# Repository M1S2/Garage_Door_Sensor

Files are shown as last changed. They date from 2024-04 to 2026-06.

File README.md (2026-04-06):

# Garage Door Sensor

This is a project to send the status of multiple garage doors (or equal) to one indoor station. This is useful if the door can't be seen from inside.
Each device (sensor and indoor station) uses an ESP12-F (ESP8266) controller that runs the software and is the WiFi transmitter. The data between the sensor and the indoor station is transmitted using ESP-Now. The indoor station acts as a gateway between ESP-Now and WiFi.

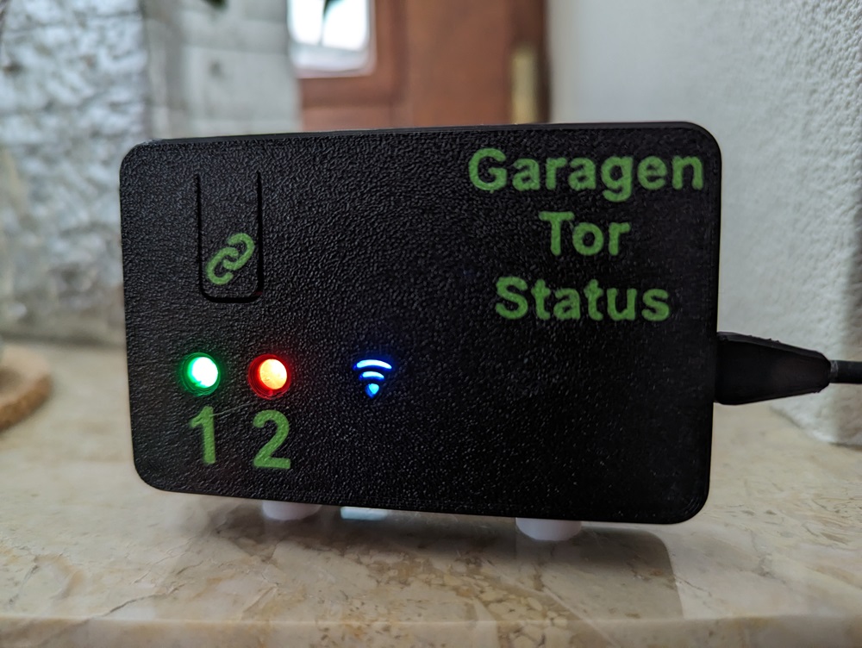
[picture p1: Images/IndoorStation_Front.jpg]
Indoor Station Front


## Building the Indoor Station
You need to build only one indoor station. It receives the state of all door sensors. The current version of the indoor station is capable of displaying 2 sensors at the same time. If you need more sensors, the indoor station must be adapted.

### PCBs and Housing
The PCBs are designed using Autodesk Fusion360 to be manufactured with toner transfer method. All design files are located in the [Electrical files for IndoorStation](IndoorStation/Electrical) subfolder.

The housing parts are also designed using Autodesk Fusion360 to be manufactured with a 3D printer. All files are located in the [Mechanical files for IndoorStation](IndoorStation/Mechanical) subfolder. Each part is needed once except the Stand (needed twice).

Also the following additional parts are necessary:
- 4x Screw M3x20
- 2x Screw M3x10
- 6x Heat Insert M3x5x5
- some acrylic glass to cover and diffuse the LEDs
- DC Power Supply (voltage e.g. 5V, is regulated down to 3.3V)

The following image shows all parts of the IndoorStation:
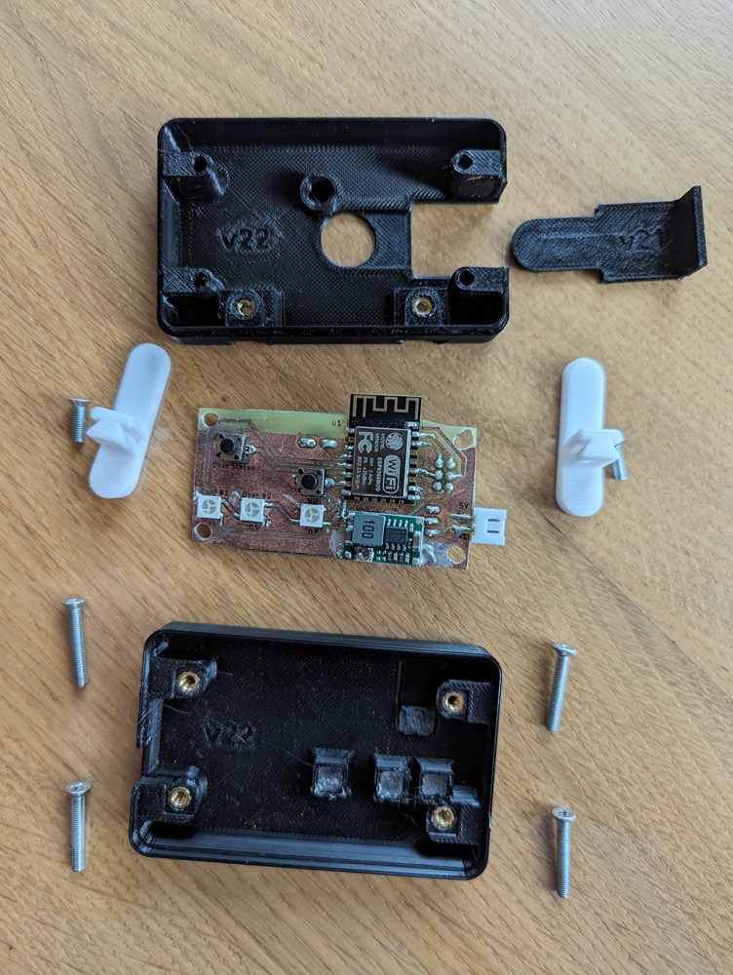
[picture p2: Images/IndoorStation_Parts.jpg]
IndoorStation Parts


### Software
The software files are located in the [Software files for IndoorStation](IndoorStation/Software) subfolder.

To build and flash the lastest software to the IndoorStation ESP12-F download and install Visual Studio Code and install the PlatformIO extension. The following page explains the whole process: https://randomnerdtutorials.com/vs-code-platformio-ide-esp32-esp8266-arduino/

The following parts must be flashed:
- Firmware: Use the `Build` and `Upload` PlatformIO tasks.
- Filesystem (containing the website files): Use the `Build Filesystem Image` and `Upload Filesystem Image` PlatformIO tasks.

## Building the Sensor
You need to build one sensor per door to monitor. The current version of the indoor station is capable of displaying 2 sensors at the same time. If you need more sensors, the indoor station must be adapted. No changes to the sensor are necessary.
### PCBs and Housing
The PCBs are designed using Autodesk Fusion360 to be manufactured with toner transfer method. All design files are located in the [Electrical files for sensor](Sensor/Electrical) subfolder.

The housing parts are also designed using Autodesk Fusion360 to be manufactured with a 3D printer. All files are located in the [Mechanical files for sensor](Sensor/Mechanical) subfolder. Each part is needed once.

Also the following additional parts are necessary:
- 4x Screw M3x30
- 4x Heat Inserts M3x5x5
- 1x Li-Ion 18650 (e.g. https://www.roboter-bausatz.de/p/bak-18650-lithium-ionen-akku-2900mah-3-6v-3-7v-erhoehter-pluspol)
- 1x Charge Modul USB-C (e.g. https://www.roboter-bausatz.de/p/lithium-batterie-lademodul-usb-c-ip2312-4-2v-5v)
- 2x Magnet for Door Mount

The following image shows all parts of the Sensor:
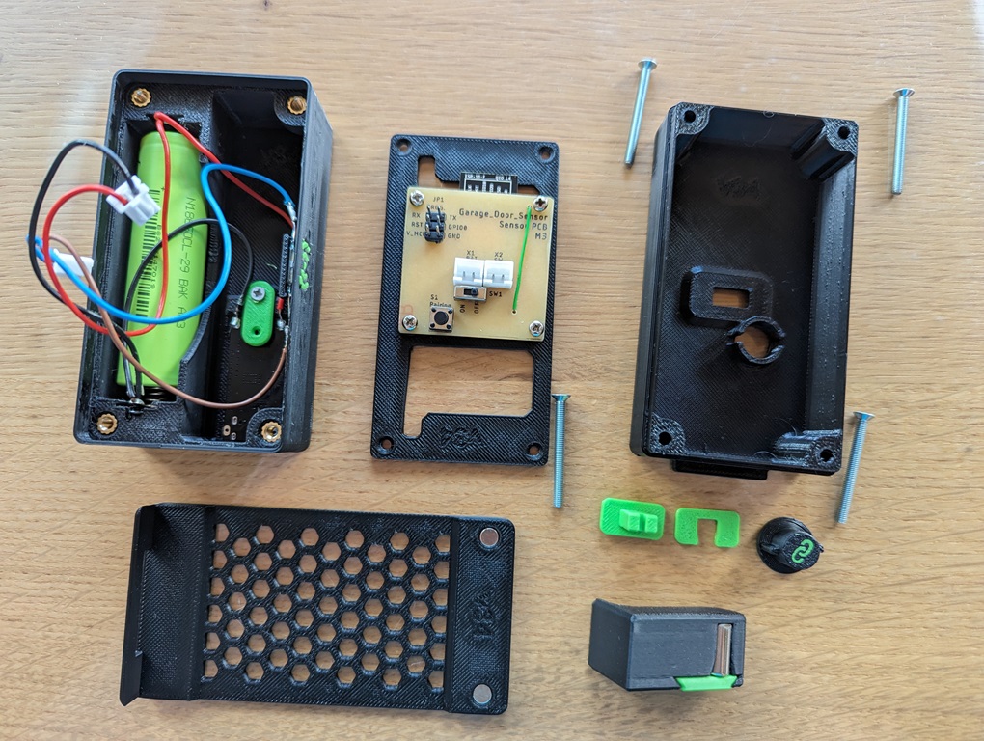
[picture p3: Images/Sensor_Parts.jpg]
Sensor Parts


### Software
The software files are located in the [Software files for Sensor](Sensor/Software) subfolder.

To build and flash the lastest software to the sensor ESP12-F download and install Visual Studio Code and install the PlatformIO extension. The following page explains the whole process: https://randomnerdtutorials.com/vs-code-platformio-ide-esp32-esp8266-arduino/

## Usage
This chapter describes the basic usage of the indoor station and sensor. It is necessary to build at least one device each before proceding.
### Charging the sensor
Switch off the sensor via the switch on the back side and connect it to an USB-C charger. Make sure the charger is capable of delivering enough energy. Otherwise the charging process will be slow.

Charger LED states:

|LED		|Meaning		|
|---|---|
|Red solid	|Powered via USB-C	|
|Green solid	|Charging complete	|

### WiFi Setup
The indoor station isn't yet connected to your local WiFi the first time you use it or after a reset.
It is necessary to connect it to the WiFi. Otherwise the following steps can't be done and the indoor station can't receive the sensor messages.
1. Power the indoor station.
2. The WiFi LED will start flashing blue for about 5 seconds (indicating that it's trying to set up a connection).
3. After this timeout, the WiFi LED will change to white, indicating that the indoor station entered access point configuration mode.
4. Search for all available WiFi networks with your smartphone or computer and connect to the one called "Garagen Tor Status AP" (configuration access point).
5. After connecting to the configuration access point, a captive portal pops up automatically (sometimes needs some seconds; otherwise directly open the IP 192.168.4.1 in your browser).
6. Select your routers WiFi network and enter the password.
7. After confirmation, the indoor station restarts and the WiFi LED is flashing blue again until the connection to the router is established.
8. When successfully connected to the WiFi, the WiFi LED is solid blue.

### Pairing of the Sensor
The pairing of the sensor can be done via the pairing button of the indoor station and the pairing button of the corresponding sensor.
1. Press the pairing button on the indoor station long. The first sensor led will start to flash blue and red.
2. Press the pairing button on the indoor station short to select the sensor slot you want to pair.
3. When the indoor station mode for the correct sensor is pairing, press and hold the pairing button on the sensor for at least 5 seconds (sensor must be switched on).
4. If the pairing of the sensor was successful, the indoor station stopped to flash blue and red.

Repeat all steps for all sensors.

**Alternative:**

The pairing of the sensor can also be done via the web pages of the indoor station.
1. Open the web page (with one of the following ways):
   a) Enter the IP address that was assigned by your router in the address bar of your browser.
   b) For Fritz!Box: enter the following host name in the address bar of your browser: `garagen-tor-status.fritz.box` (or scan the QR code below)
2. Change to the configuration page (gear icon)
3. Enter the MAC address of the sensor to pair in the textbox of the corresponding sensor and click submit.
4. All messages of this sensor are now received for the sensor index where the MAC address was entered.

Repeat steps 3. and 4. for all sensors.

Indoor Station web page QR Code

### Mounting the Sensor and Magnet
To mount the sensor and magnet to the garage door:
1. Insert a magnet inside the `Magnet_Mount` part and assemble the `Magnet_Mount_Lid` with a screw.
2. Take the full assembled sensor, the `Door_Mount` part and the `Magnet_Mount`.
3. Switch off the sensor using the switch on the back side.
4. Go inside the garage and close the door.
5. Fix the `Door_Mount` part with double sided tape or power stripes to the door frame. Make sure, there is a small gap of about 3 mm to the metal blade of the door (the outermost moving part). An example position is shown in the following pictures:
6. Insert the sensor in the `Door_Mount`. The two magnets on the `Door_Mount` hold the sensor in place. The counterparts are the two upper screws in the sensor housing.
7. Fix the `Magnet_Mount` part with double sided tape or power stripes to the door blade. Make sure, the magnet is near the icon on the side of the sensor (indicating the position of the reed switch).
8. Open and close the door to make sure, the magnet is moved from and to the sensor, without any mechanical contact. If the door is closed, the magnet must reside near the sensor again.
9. Remove the sensor from the `Door_Mount`, switch the sensor on using the switch on the back side and insert the sensor in the `Door_Mount` again.

<p>
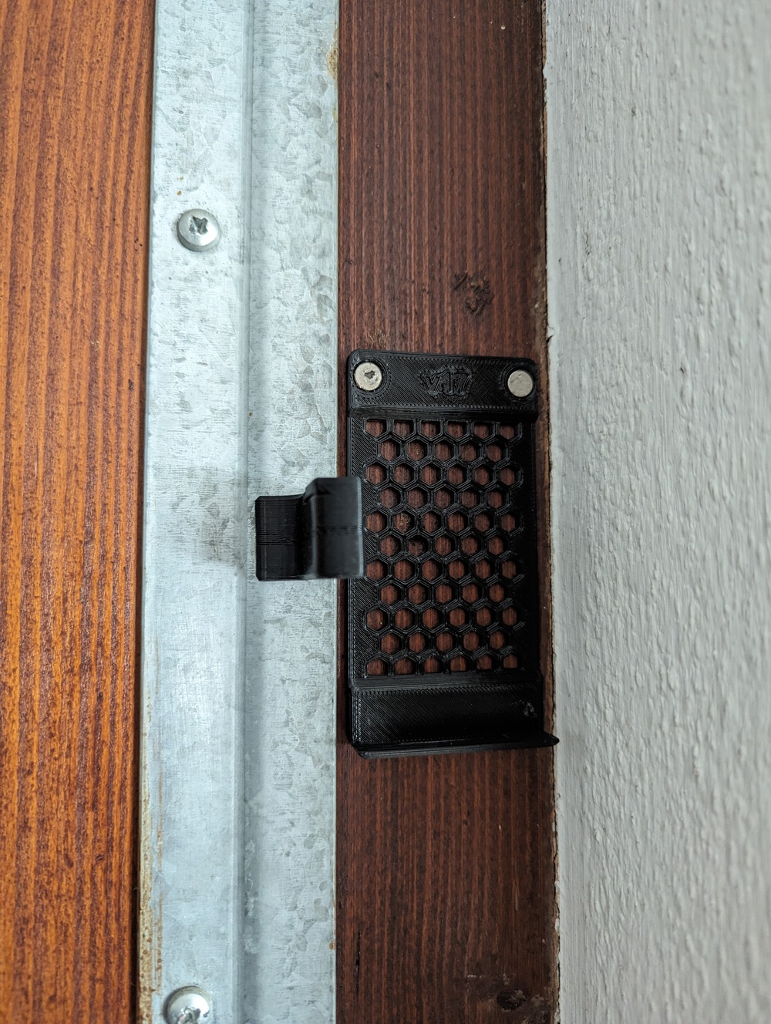
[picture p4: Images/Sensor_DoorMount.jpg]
  
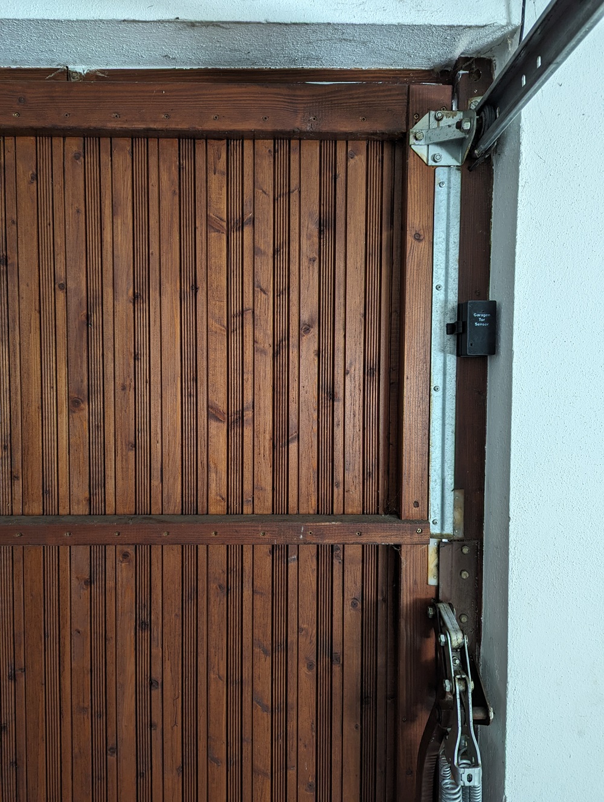
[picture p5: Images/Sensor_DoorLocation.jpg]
  
</p>

### Testing
To test the whole system, open and close one garage door after another and monitor the displayed state on the indoor station.
- When the first door is closed, the LED "1" on the indoor station will be red.
- When the first door is open, the LED "1" on the indoor station will be green.
- When the second door is closed, the LED "2" on the indoor station will be red.
- When the second door is open, the LED "2" on the indoor station will be green.
- All actual door states can also be monitored via the web page (overview page). To open the the web page, follow the steps at the ["Pairing the sensor" chapter](#pairing-of-the-sensor).

## LED States
| Led		 | Color 	 | State | Description						 |
|---|---|---|---|
| Sensor #1 / #2 | red 		 | solid | Door is closed, battery ok 				 |
| Sensor #1 / #2 | red 		 | flashing | Door is closed, battery empty 				 |
| Sensor #1 / #2 | green 	 | solid | Door is open, battery ok 					 |
| Sensor #1 / #2 | green 	 | flashing | Door is open, battery empty 				 |
| Sensor #1 / #2 | purple 	  | solid | Sensor mode is charging 					 |
| Sensor #1 / #2 | red / blue	| blinking | Sensor mode is pairing 					 |
| Sensor #1 / #2 | / 		 |  off | Either no message received yet, or sensor mode is disabled |
| Wifi  	 | blue 	 | flashing | Trying to connect to WiFi 				 	|
| Wifi  	 | blue 	 | solid | Connected to WiFi 					 |
| Wifi  	 | red 		 | solid | Connection to WiFi failed 				 |
| Wifi  	 | white 	 | solid | Configuration access point is open 			 |
| All  		 | yellow 	  | blinking | OTA Update is in progress 					 |
| All  		 | green 	 | solid | OTA Update is in ready 					 |
| All  		 | red 		 | solid | OTA Update is in failed 					 |

## Button Reactions:
| Button  | Click Type  | Precondition | Description |
|---|---|---|---|
| Reset | long press  | always | Memory data and WiFi credentials are erased |
| Pairing | long press  | no sensor is in pairing mode | Set first sensor to pairing mode (start pairing) |
| Pairing | long press  | at least one sensor is in pairing mode  | Set all sensors that are in pairing mode back to normal mode (end pairing)  |
| Pairing | short click | no sensor is in pairing mode | Do nothing |
| Pairing | short click | at least one sensor is in pairing mode  | Find the first sensor with pairing mode. Set it to normal mode and set the next sensor to pairing mode. If it was the last sensor begin with the first again. |

## Sensor Modes
| Mode 		 | Description 													 				|
|---|---|
| Normal	 | All messages are received, everything is saved, LED on								 			|
| Disabled	 | All messages are ignored, nothing is saved, LED off										 		|
| Charging	 | All messages are ignored, nothing is saved, LED in different color								 		|
| Only Display  | Messages are only displayed via the LED, nothing is saved											 |
| Pairing	 | Message from Indoor Station to corresponding sensor to configure the MAC address in the sensor, LED flashes red and blue, nothing is saved	  |

## Developer Hints
- The sensor is designed to consume as less power as possible. Therefore the ESP8266 on the sensor is only switched on when the pin state changed and only as long until the data is sent to the indoor station.
- The sensor trys to send the data on all available WiFi channels until success. The most common used channels are tried first.
- The indoor station can be updated using over the air (OTA) updates. The first time the firmware must be flashed via serial, the OTA is available by navigating to `garagen-tor-status.fritz.box/update` in the browser.
- Accessing the indoor station web pages via the IP address (e.g. 192.168.x.x) isn't really intuitive. The FritzBox offers the possibility to alternatively navigate to `garagen-tor-status.fritz.box`. The correct IP address is then resolved via DNS.

## Further Improvements
- Move the pairing button of the Indoor Station to the backside of the housing (not used very often, cleaner front side) 
- Remove ConnectorLid of Indoor Station housing (software updates are possible via OTA, no need to open the housing very often)
- Remove the on/off switch from the Indoor Station PCB (not really used, disconnecting power supply is enough)

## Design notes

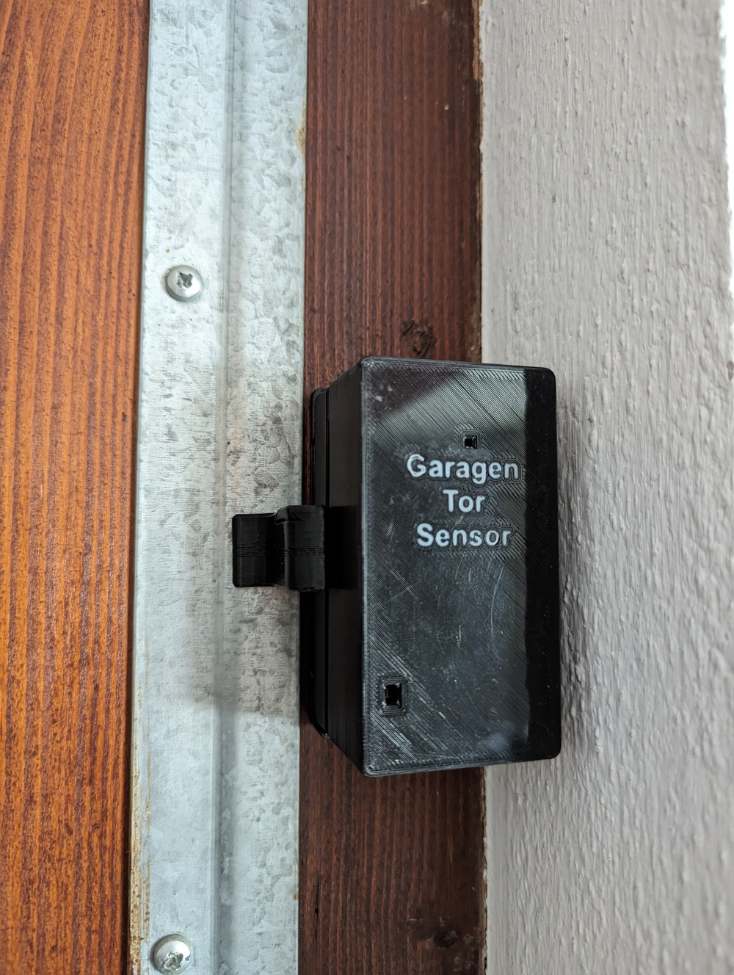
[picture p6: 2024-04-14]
Images/Sensor_DoorClosed_MagnetHolder.jpg

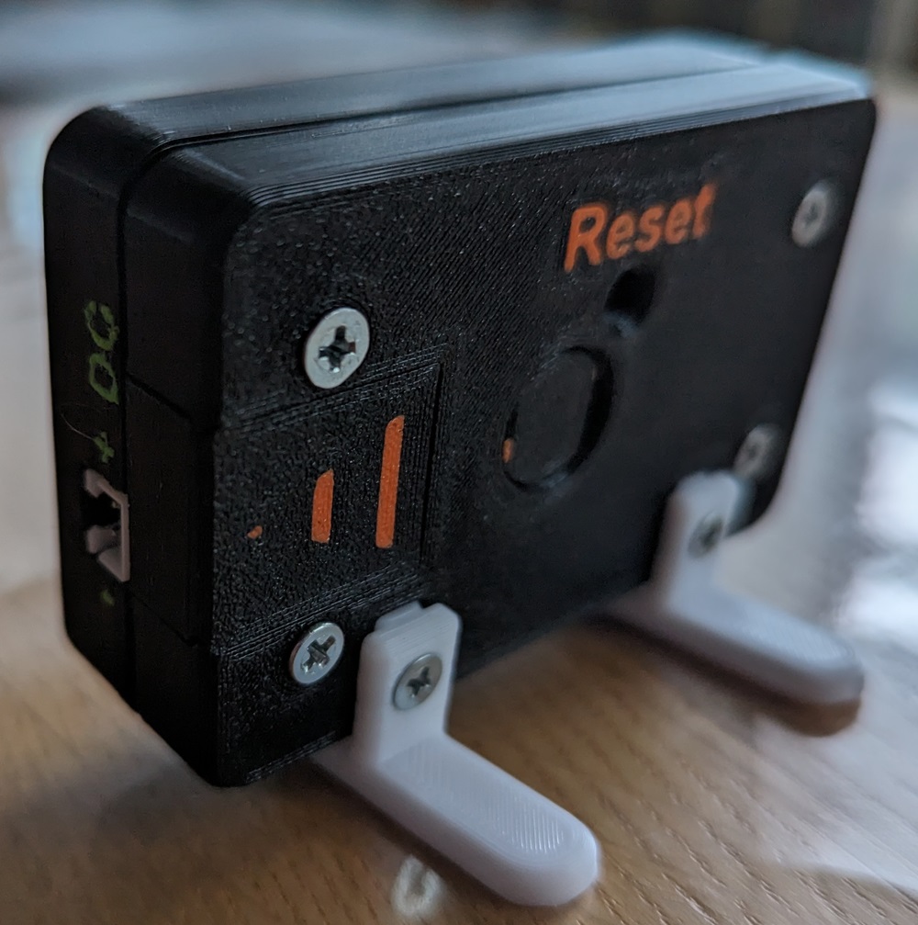
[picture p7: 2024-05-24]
Images/IndoorStation_Back.jpg

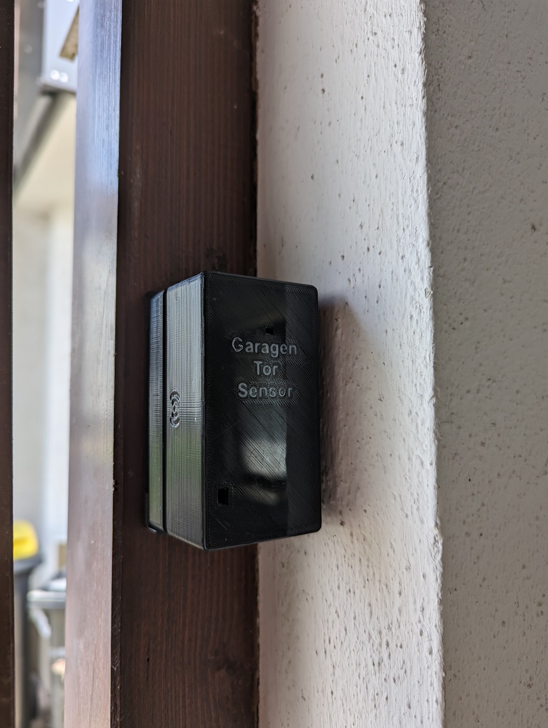
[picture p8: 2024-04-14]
Images/Sensor_DoorOpen.jpg

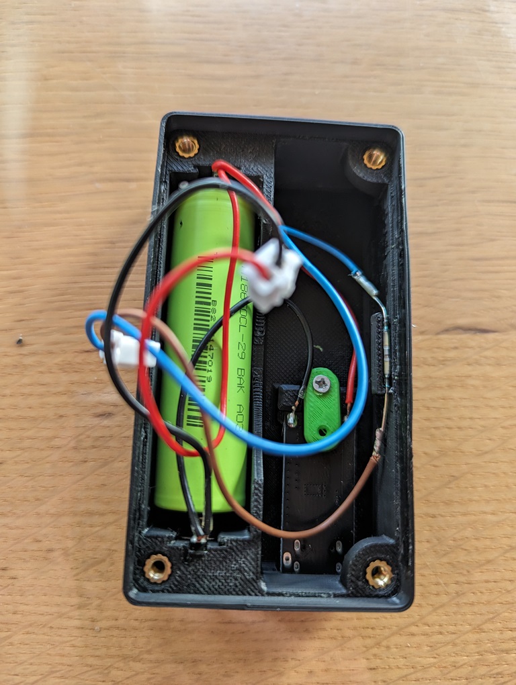
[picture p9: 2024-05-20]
Images/Sensor_FrontLid_Battery.jpg

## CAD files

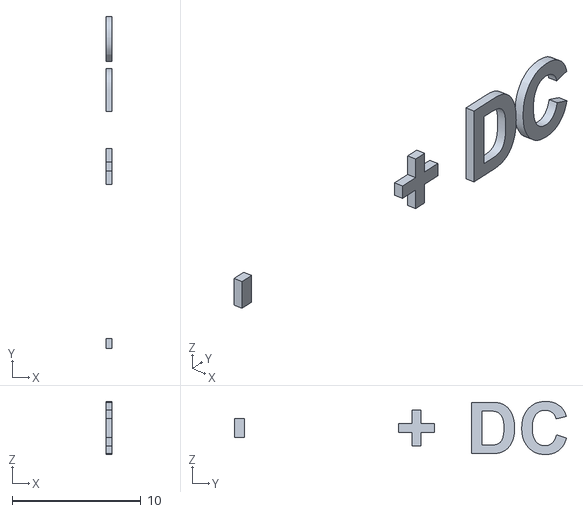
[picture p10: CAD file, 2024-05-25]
IndoorStation/Mechanical/Front_Lid_Text_Side_M3.stl
0.5 x 25.8 x 4.14

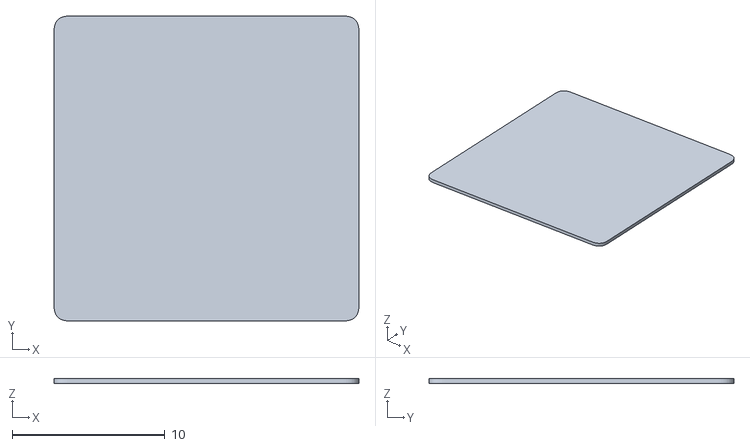
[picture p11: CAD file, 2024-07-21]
IndoorStation/Mechanical/QR_Code/qrcode-base.stl
20.0 x 20.0 x 0.3

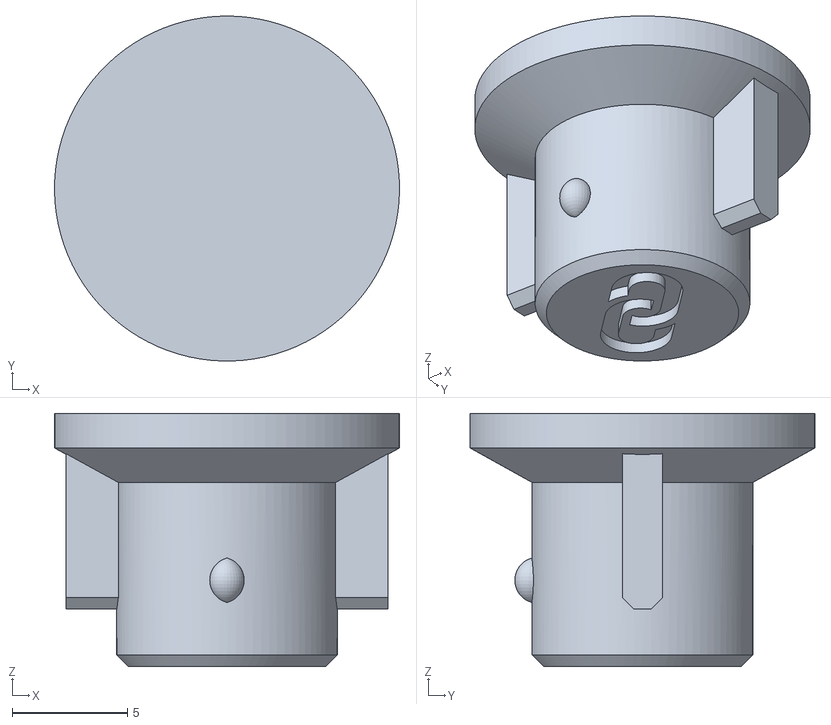
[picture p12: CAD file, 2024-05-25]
Sensor/Mechanical/Pairing_Button_M3.stl
15.0 x 15.0 x 11.0

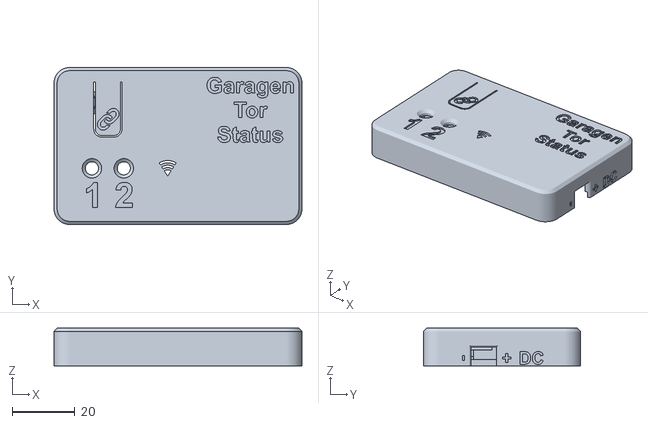
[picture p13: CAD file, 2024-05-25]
IndoorStation/Mechanical/Front_Lid_M3.stl
79.0 x 50.0 x 12.0

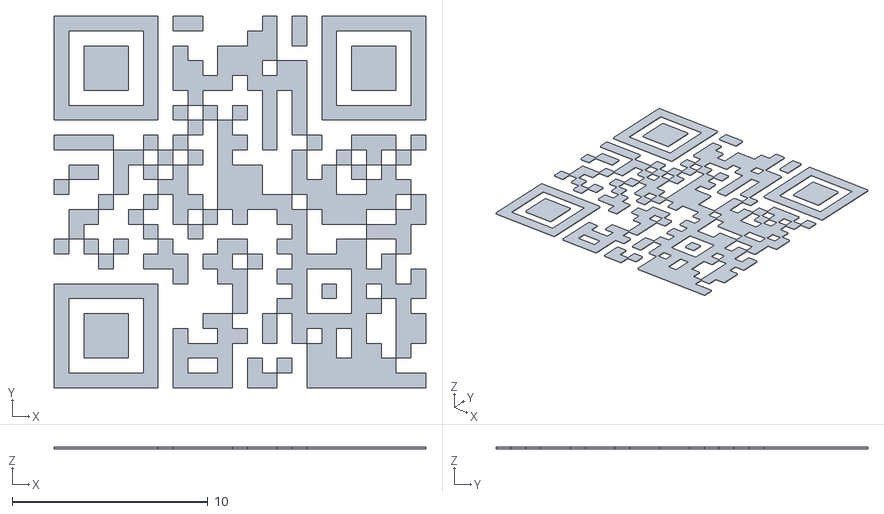
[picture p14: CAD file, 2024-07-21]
IndoorStation/Mechanical/QR_Code/qrcode.stl
19.0 x 19.0 x 0.1

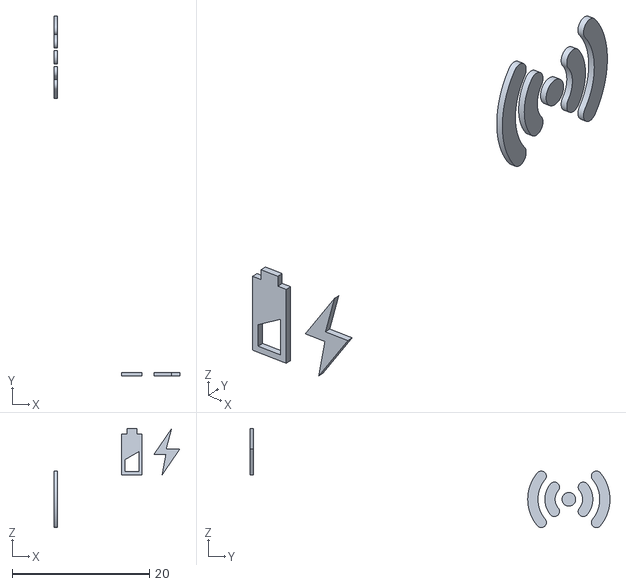
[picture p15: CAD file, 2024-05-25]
Sensor/Mechanical/Front_Lid_Text_Side_M3.stl
18.4 x 52.5 x 14.5

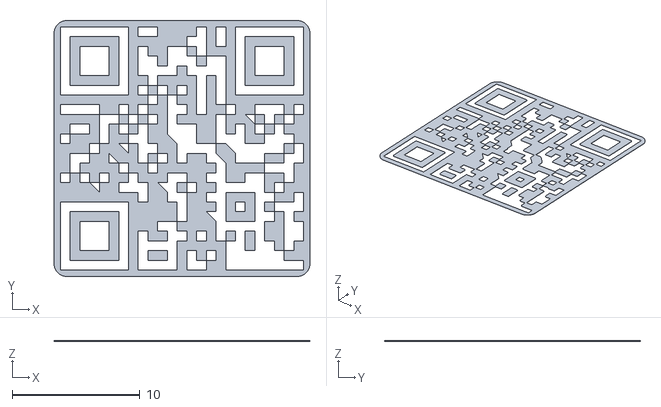
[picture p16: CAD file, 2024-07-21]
IndoorStation/Mechanical/QR_Code/qrcode-frame.stl
20.0 x 20.0 x 0.1

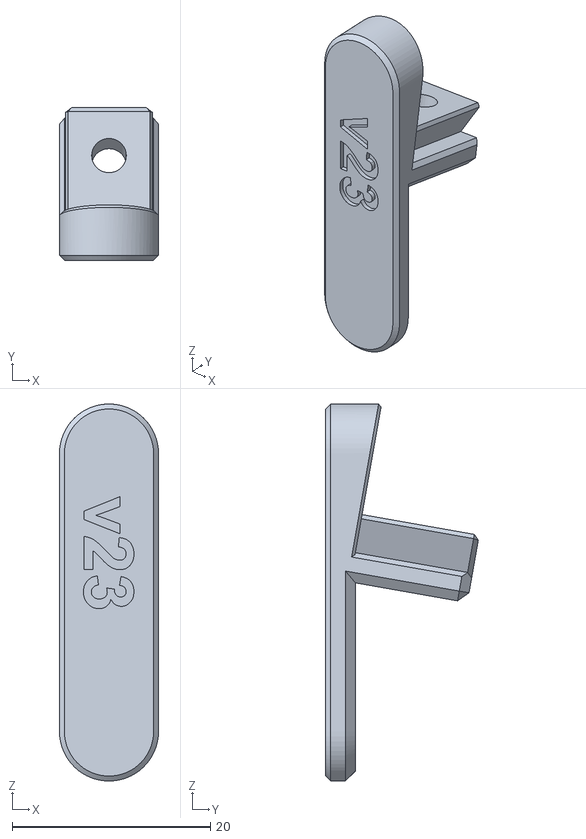
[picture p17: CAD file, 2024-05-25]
IndoorStation/Mechanical/Stand_M3.stl
10.0 x 15.4 x 38.0

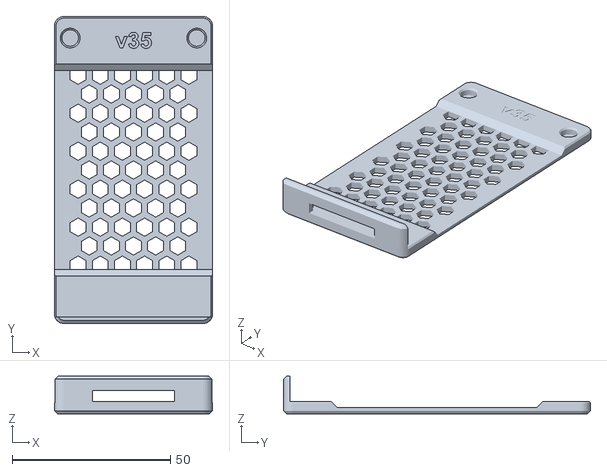
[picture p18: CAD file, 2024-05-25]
Sensor/Mechanical/Door_Mount_M3.stl
50.0 x 97.0 x 12.0

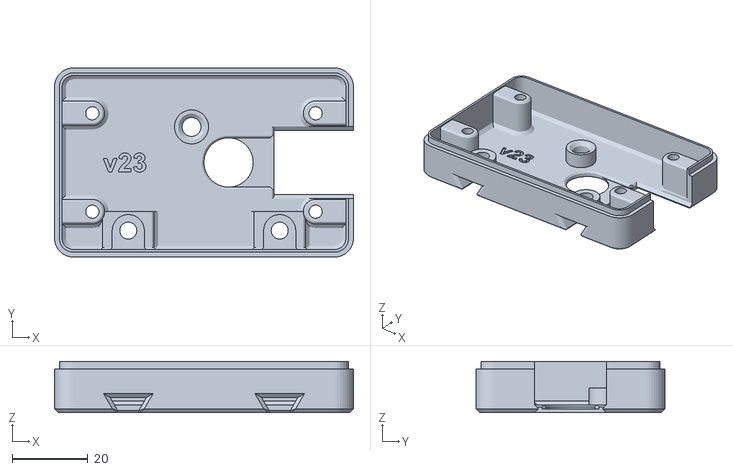
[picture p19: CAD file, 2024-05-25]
IndoorStation/Mechanical/Back_Lid_M3.stl
79.0 x 50.0 x 13.5

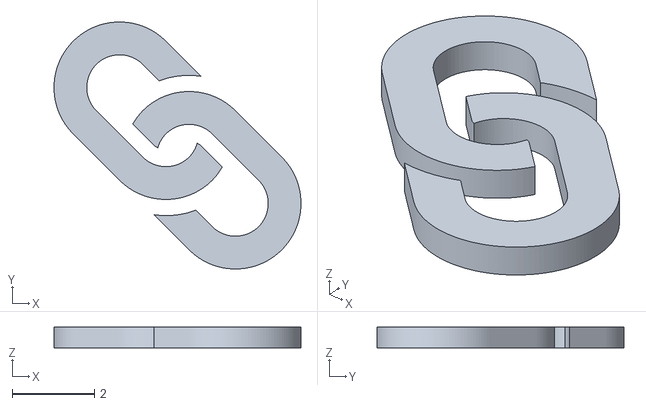
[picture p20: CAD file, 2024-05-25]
Sensor/Mechanical/Pairing_Button_Text_M3.stl
6.02 x 6.02 x 0.5

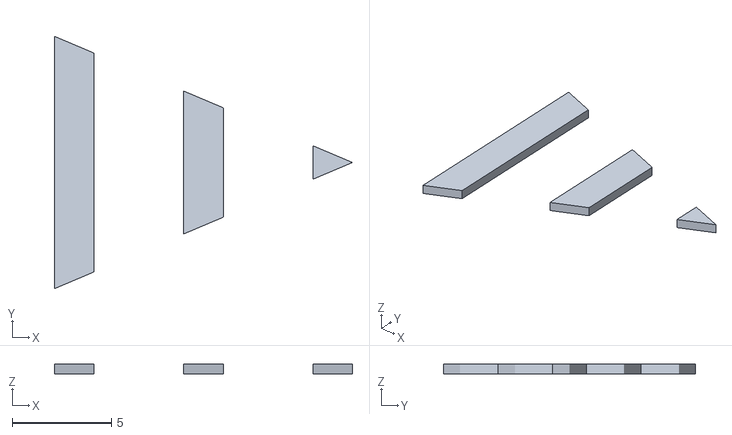
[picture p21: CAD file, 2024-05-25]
IndoorStation/Mechanical/Connector_Lid_Text_M3.stl
15.0 x 12.7 x 0.5

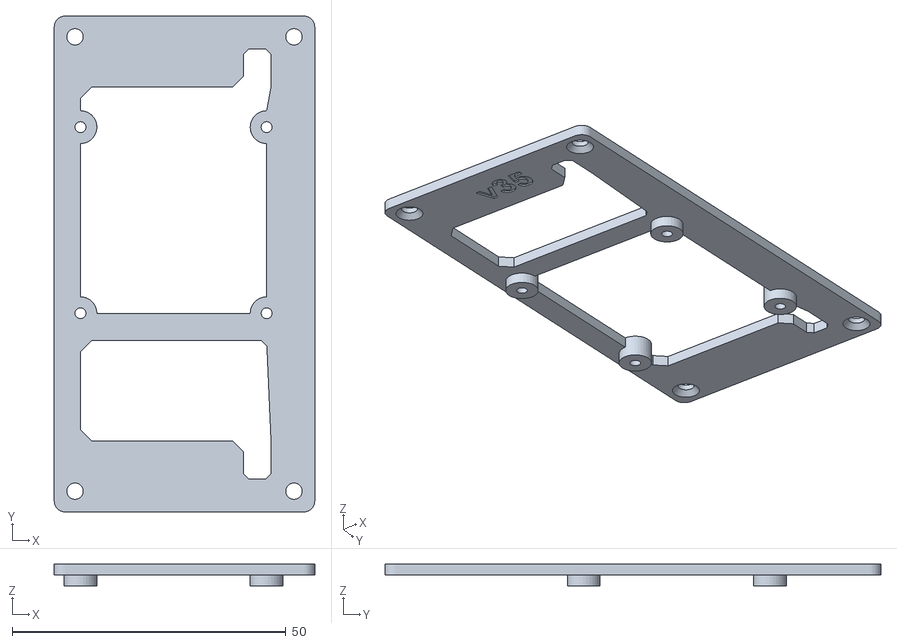
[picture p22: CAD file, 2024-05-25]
Sensor/Mechanical/PCB_Holder_M3.stl
47.6 x 90.6 x 4.00

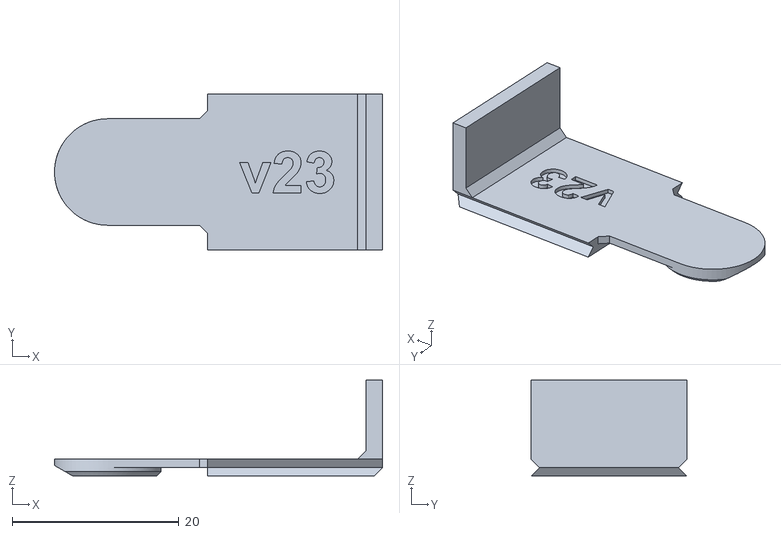
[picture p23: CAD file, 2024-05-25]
IndoorStation/Mechanical/Connector_Lid_M3.stl
39.4 x 18.7 x 11.5

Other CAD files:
Sensor/Mechanical/Back_Lid_M3.stl
IndoorStation/Mechanical/Back_Lid_Text_M3.stl
Sensor/Mechanical/Front_Lid_M3.stl
IndoorStation/Mechanical/Front_Lid_Text_M3.stl
IndoorStation/Mechanical/Back_Lid_M3.f3d
IndoorStation/Mechanical/Connector_Lid_M3.f3d
IndoorStation/Mechanical/Front_Lid_M3.f3d
IndoorStation/Mechanical/Stand_M3.f3d
Sensor/Mechanical/Back_Lid_M3.f3d
Sensor/Mechanical/Back_Lid_Text_M3.stl
Sensor/Mechanical/Door_Mount_M3.f3d
Sensor/Mechanical/Front_Lid_M3.f3d
Sensor/Mechanical/Front_Lid_Text_M3.stl
Sensor/Mechanical/LoadingModuleClamp_M3.f3d
Sensor/Mechanical/LoadingModuleClamp_M3.stl
Sensor/Mechanical/Magnet_Mount_Lid_M3.f3d
Sensor/Mechanical/Magnet_Mount_Lid_M3.stl
Sensor/Mechanical/Magnet_Mount_M3.f3d
Sensor/Mechanical/Magnet_Mount_M3.stl
Sensor/Mechanical/Pairing_Button_M3.f3d
Sensor/Mechanical/Switch_Slider_Clamp_M3.f3d
Sensor/Mechanical/Switch_Slider_Clamp_M3.stl
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

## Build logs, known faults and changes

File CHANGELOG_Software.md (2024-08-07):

# Garagen Door Sensor - Software Changelog

## v2.3

> Sensor
- Nothing changed (equal to v2.2)

> Indoor Station
- Added a QR code for the indoor station web page to the Readme
- Adaptions to the Readme
- Bugfix for sensor_history.js (chart was incomplete or contained wrong data when incomplete chunks were received)
- Added version tag for the webpages

## v2.2

> Sensor
- Disabled debug output to save power

> Indoor Station
- Added define to disable debug output

## v2.1

> Sensor
- Nothing changed (equal to v2.0)

> Indoor Station
- Make sure that all data is displayed in all charts after updating
- Removed data labels from charts
- Bugfixes for reset

> Documentation
- Update README.md (color for charging LED)
- Updated some images for Readme

## v2.0

> Sensor & Indoor Station
- Added feature to pair sensor with indoor station (send sensor MAC to indoor station)

> Sensor
- Combine methods to send pairing and status data
- Switch off and on Wifi to improve ADC accuracy

> Indoor Station
- Reactivated and renamed button to select pairing mode

> Documentation
- Updated Readme and some images

## v1.0

> Sensor
- Initial version

> Indoor Station
- Initial version

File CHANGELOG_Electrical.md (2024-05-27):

# Garagen Door Sensor - Electrical Changelog

## PCB_M3

> Sensor
- Added pairing switch

> Indoor Station
- Changed name of show status button to pairing button
- Removed WiFi button

## PCB_M2

> Sensor
- Added resistor R10 (pull-down for door switch)
- Added hole markers

> Indoor Station
- Added vias to button pads for better assembly
- Added hole markers

## PCB_M1

> Sensor
- Initial version

> Indoor Station
- Initial version

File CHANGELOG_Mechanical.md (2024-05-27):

# Garagen Door Sensor - Mechanical Changelog

## HW_M3

> Sensor
- Made pairing button slightly shorter

> Indoor Station
- Slight adaptions to Front_Lid, Back_Lid and Connector_Lid

## HW_M2

> Sensor
- Added pairing button
- Updated PCB to PCB_M3
- Replaced loading module by 3A variant
- Adapted holes for magnets in Door_Mount
- Changed accent color to green

> Indoor Station
- Changed icon for pairing button
- Updated PCB
- Removed WiFi button
- Changed accent color to green

## HW_M1

> Sensor
- Initial version

> Indoor Station
- Initial version

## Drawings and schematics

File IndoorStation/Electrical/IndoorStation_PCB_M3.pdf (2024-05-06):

# Power Supply Input (e.g. 5V)

# Voltage Regulation to 3,3V

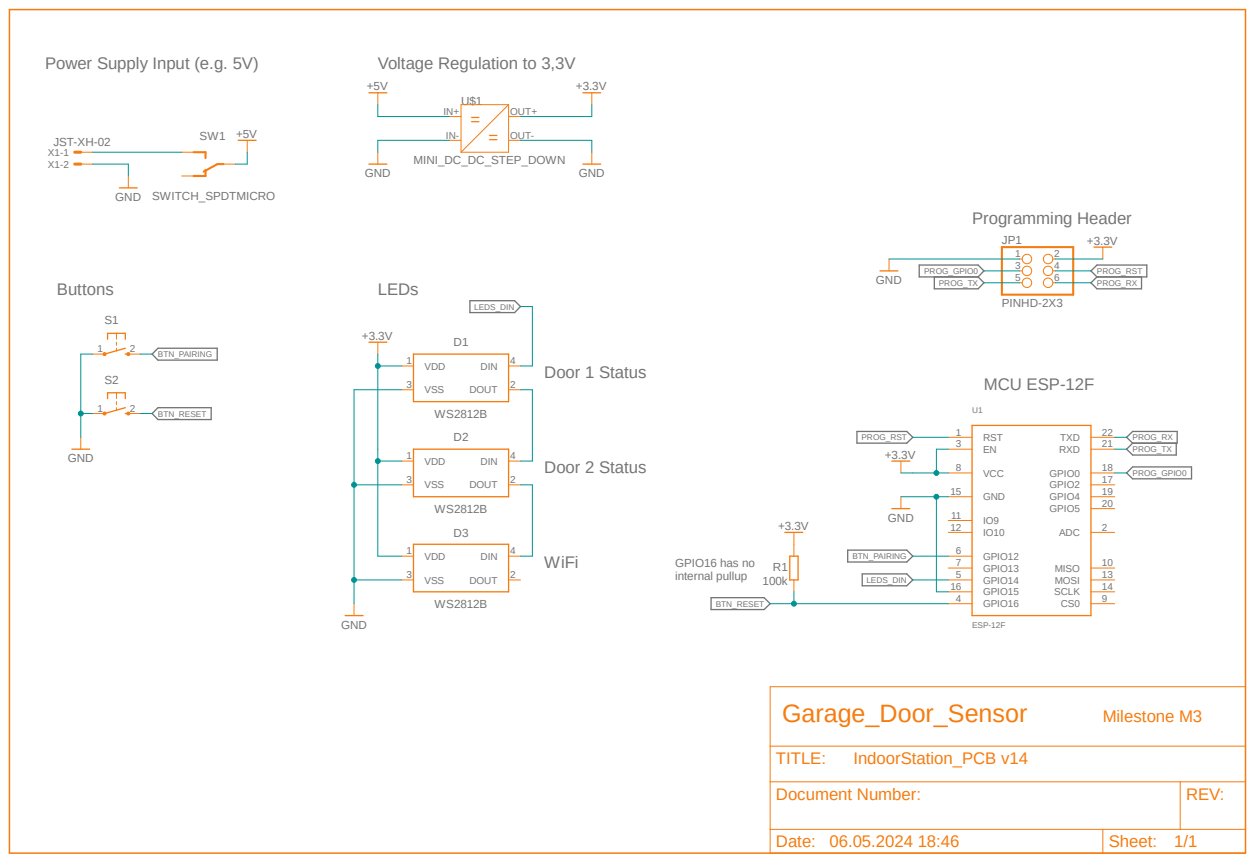
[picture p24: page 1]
Programming Header; MCU ESP-12F; Buttons; LEDs; WiFi; Door 1 Status; Door 2 Status; GPIO16 has no internal pullup; ESP-12F; GND; PINHD-2X3; SWITCH_SPDTMICRO; JST-XH-02; MINI_DC_DC_STEP_DOWN; U1RST 1; ADC; GPIO16 4; GPIO14 5; GPIO12 6; GPIO13 7; VCC 8; MISO; MOSI; SCLK; 14 GND 15; GPIO15 16; GPIO2; 17 GPIO0; GPIO4; GPIO5; 20 RXD; 21 TXD; DOUT; 2 DIN; 4 VDD 1; VSS 3; OUT+; OUT-; PROG_RX; PROG_TX; PROG_RST; PROG_GPIO0; BTN_PAIRING; LEDS_DIN; BTN_RESET; Garage_Door_Sensor; Milestone M3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

Document Number: | REV:

Date: 06.05.2024 18:46 | Sheet: 1/1

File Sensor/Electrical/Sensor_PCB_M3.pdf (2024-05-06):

## Battery Input

## Edge Detection

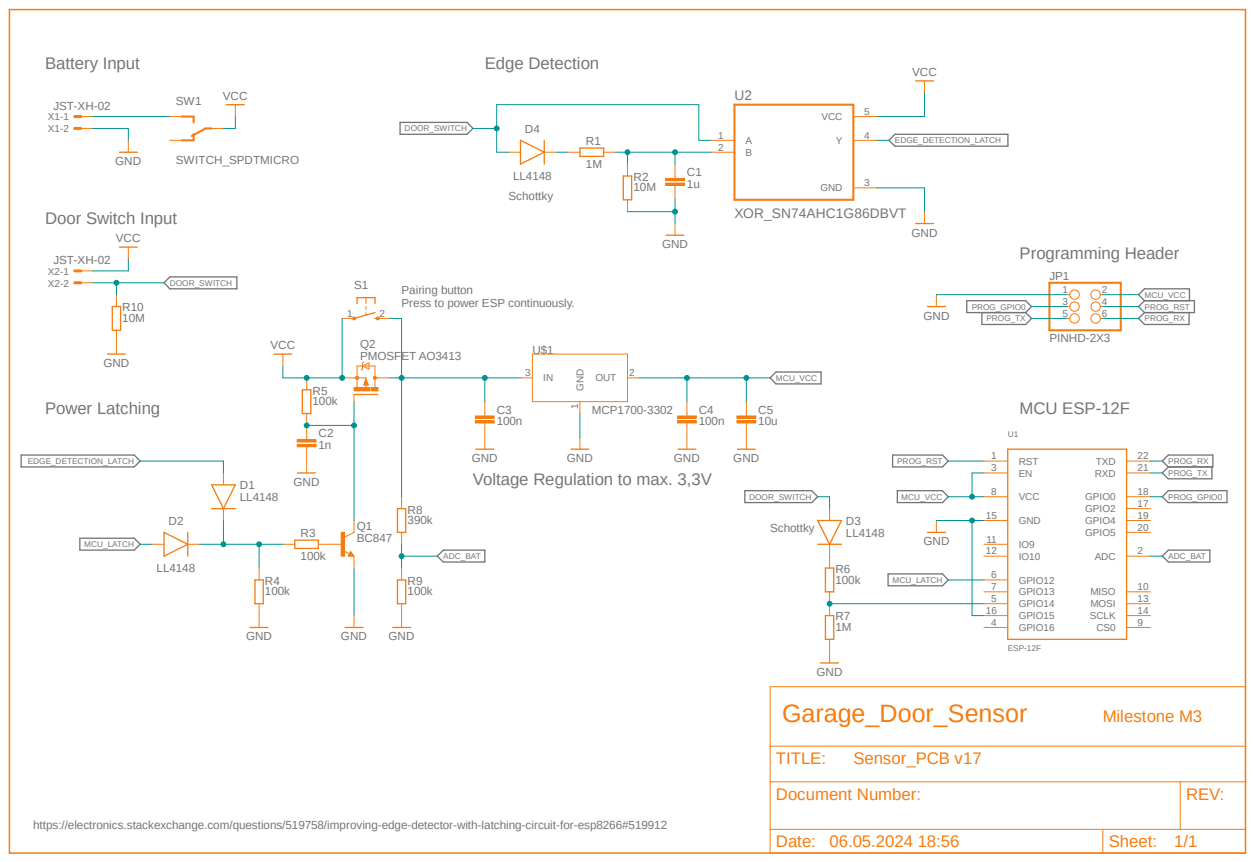
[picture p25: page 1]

Pairing button
Press to power ESP continuously.

Voltage Regulation to max. 3,3V

Document Number: | REV:

https://electronics.stackexchange.com/questions/519758/improving-edge-detector-with-latching-circuit-for-esp8266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

Date: 06.05.2024 18:56 | Sheet: 1/1

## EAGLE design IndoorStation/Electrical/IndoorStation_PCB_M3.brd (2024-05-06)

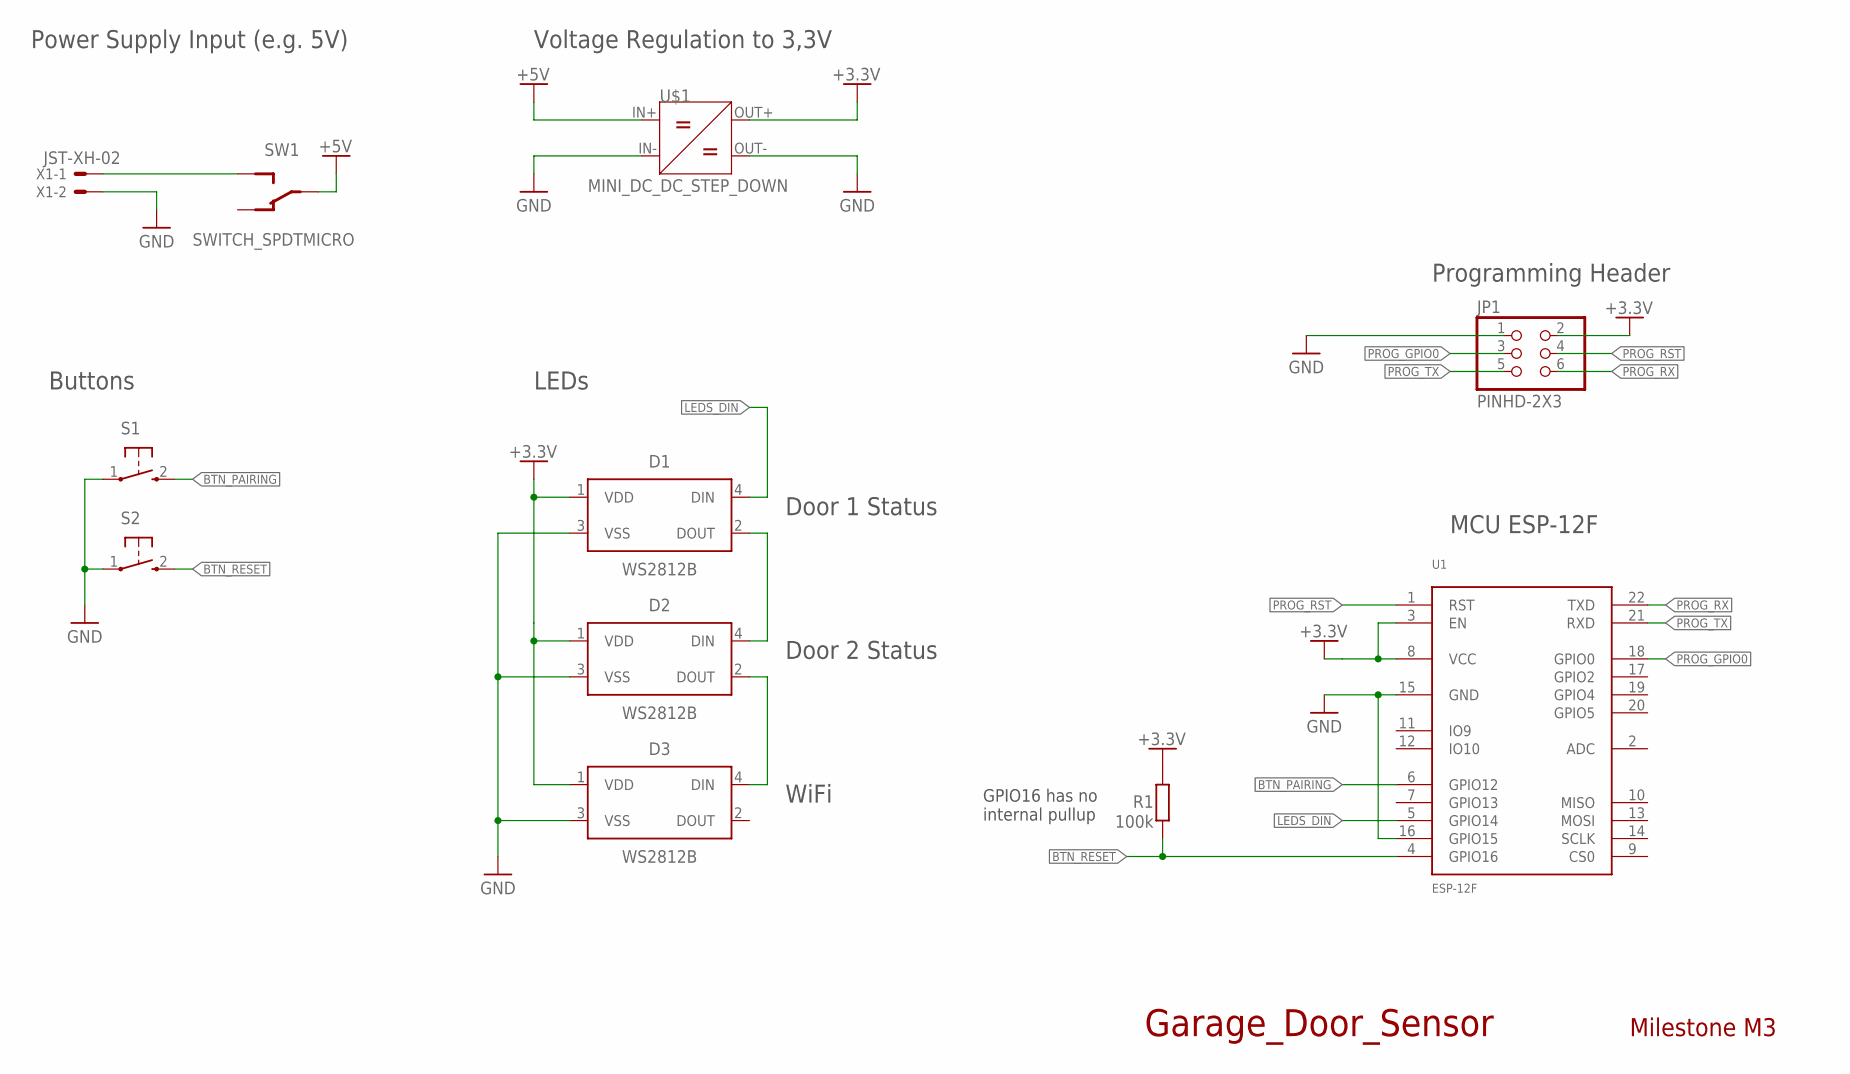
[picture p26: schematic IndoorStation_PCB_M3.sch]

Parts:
D1, D2, D3: WS2812B
JP1: PINHD-2X3; 2X03
R1: 100k; R0805
S1, S2: KURZHUBTASTER; B3F-10XX
SW1: SWITCH_SPDTMICRO; MICROSWITCH_SPDT
U1: ESP-12F
U$1: MINI_DC_DC_STEP_DOWN
X1: JST-XH-02; JST-XH-02-EDGE

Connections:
+3.3V: D1.1 (VDD), D2.1 (VDD), D3.1 (VDD), JP1.2, R1.2, U1.3 (EN), U1.8 (VCC), U$1.OUT+
+5V: SW1.P$2, U$1.IN+
BTN_PAIRING: S1.2 (S), U1.6 (GPIO12)
BTN_RESET: R1.1, S2.2 (S), U1.4 (GPIO16)
GND: D1.3 (VSS), D2.3 (VSS), D3.3 (VSS), JP1.1, S1.1, S2.1, U1.15 (GND), U1.16 (GPIO15), U$1.IN-, U$1.OUT-, X1.P$2
LEDS_DIN: D1.4 (DIN), U1.5 (GPIO14)
unnamed: D1.2 (DOUT), D2.4 (DIN)
unnamed: D2.2 (DOUT), D3.4 (DIN)
unnamed: SW1.P$1, X1.P$1
PROG_GPIO0: JP1.3, U1.18 (GPIO0)
PROG_RST: JP1.4, U1.1 (RST)
PROG_RX: JP1.6, U1.22 (TXD)
PROG_TX: JP1.5, U1.21 (RXD)

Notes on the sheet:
Power Supply Input (e.g. 5V)
Programming Header
MCU ESP-12F
Voltage Regulation to 3,3V
Buttons
LEDs
WiFi
Door 1 Status
Door 2 Status
Garage_Door_Sensor
Milestone M3
GPIO16 has no internal pullup

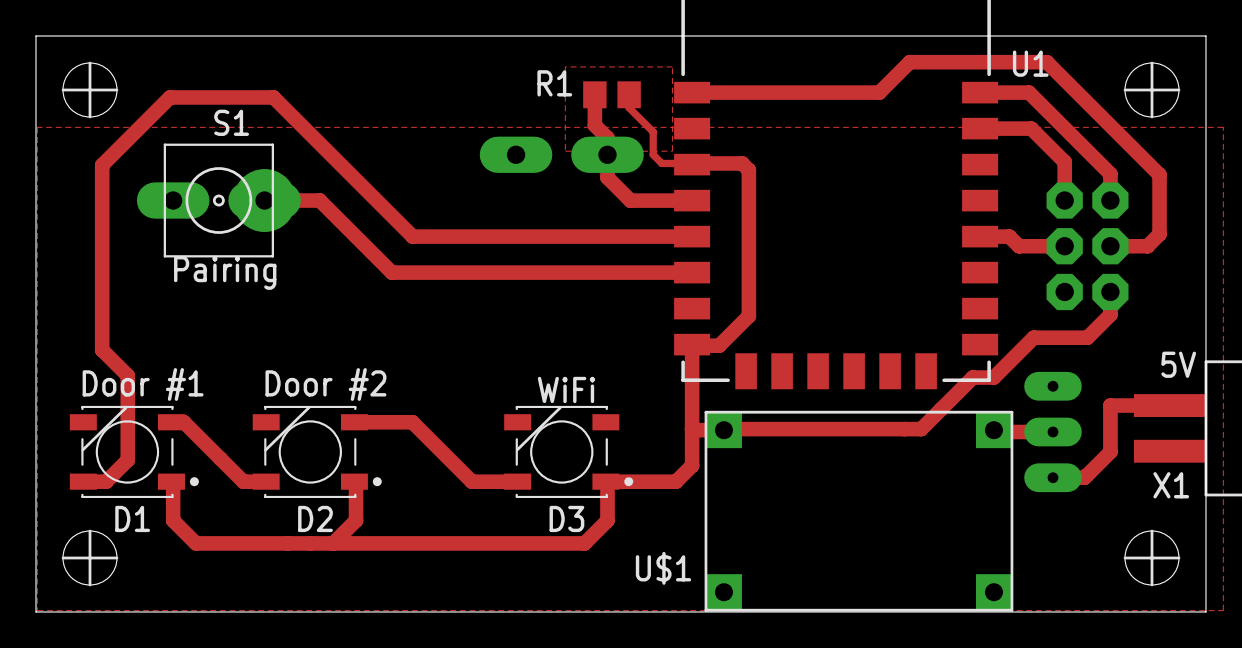
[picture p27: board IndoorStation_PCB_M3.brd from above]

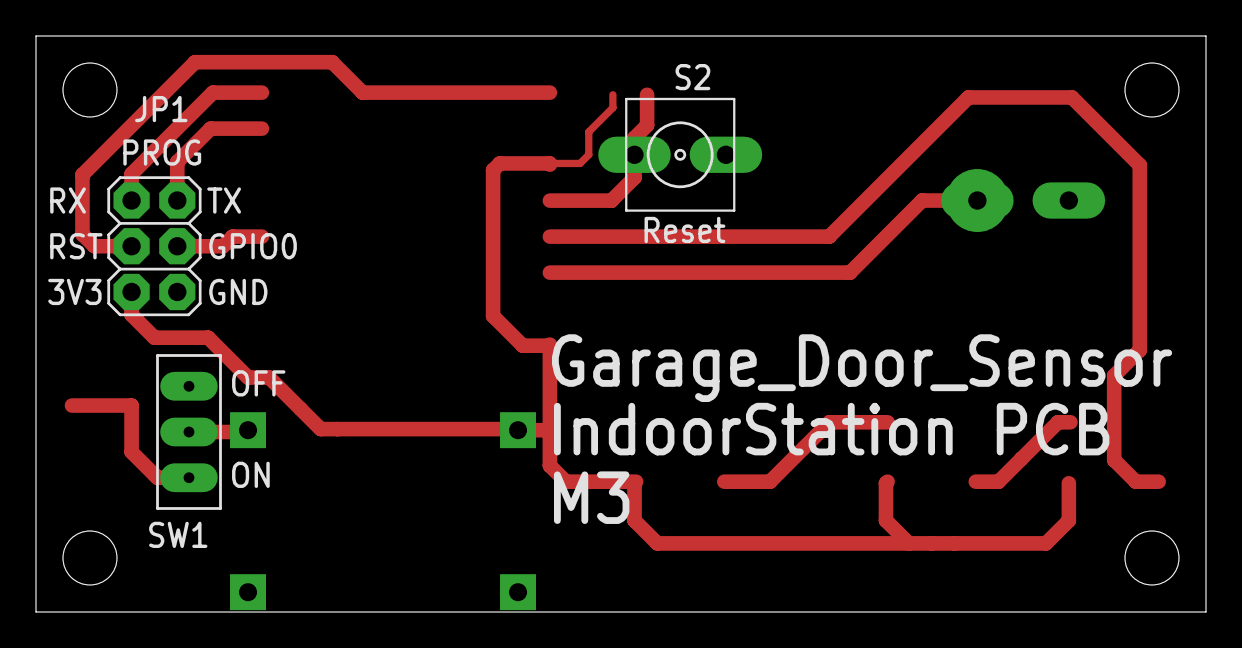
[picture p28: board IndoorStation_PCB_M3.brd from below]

Board: 2 copper layers, 65.0 x 32.0 mm, 11 parts (3 on the bottom side), 13 nets.

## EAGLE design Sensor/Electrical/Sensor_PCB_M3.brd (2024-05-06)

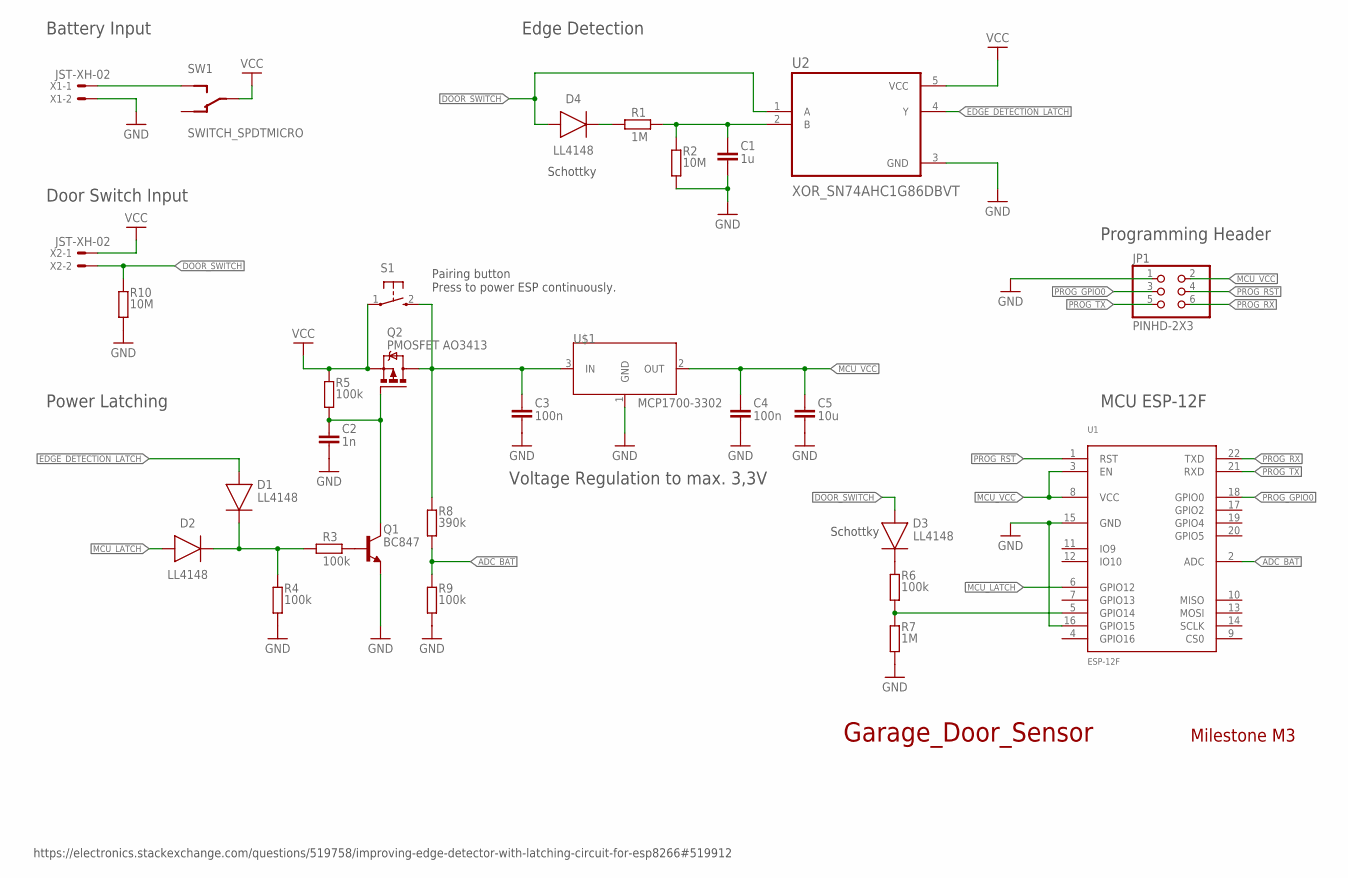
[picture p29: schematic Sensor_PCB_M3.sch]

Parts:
C1: 1u; CAPC2012X110
C2: 1n; CAPC2012X110
C3, C4: 100n; CAPC2012X110
C5: 10u; CAPC2012X110
D1, D2, D3, D4: LL4148; DIOMELF3516
JP1: PINHD-2X3; 2X03
Q1: BC847; SOT95P237X112-3N
Q2: PMOSFET AO3413; SOT23
R1, R7: 1M; R0805
R2, R10: 10M; R0805
R3, R4, R5, R6, R9: 100k; R0805
R8: 390k; R0805
S1: KURZHUBTASTER; B3F-10XX
SW1: SWITCH_SPDTMICRO; MICROSWITCH_SPDT
U1: ESP-12F
U2: XOR_SN74AHC1G86DBVT; SOT95P280X145-5N
U$1: MCP1700-3302; SOT23
X1, X2: JST-XH-02; JST-XH-02-PACKAGE-LONG-PAD

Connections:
ADC_BAT: R8.1, R9.2, U1.2 (ADC)
DOOR_SWITCH: D3.2 (A), D4.2 (A), R10.2, U2.1 (A), X2.2
EDGE_DETECTION_LATCH: D1.2 (A), U2.4 (Y)
GND: C1.2, C2.2, C3.2, C4.2, C5.2, JP1.1, Q1.2 (E), R2.1, R4.1, R7.1, R9.1, R10.1, U1.15 (GND), U1.16 (GPIO15), U2.3 (GND), U$1.1 (GND), X1.2
MCU_LATCH: D2.2 (A), U1.6 (GPIO12)
MCU_VCC: C4.1, C5.1, JP1.2, U1.3 (EN), U1.8 (VCC), U$1.2 (OUT)
unnamed: C1.1, R1.2, R2.2, U2.2 (B)
unnamed: D4.1 (C), R1.1
unnamed: Q1.1 (B), R3.2
unnamed: D1.1 (C), D2.1 (C), R3.1, R4.2
unnamed: C2.1, Q1.3 (C), Q2.1 (G), R5.1
unnamed: D3.1 (C), R6.2
unnamed: R6.1, R7.2, U1.5 (GPIO14)
unnamed: SW1.P$1, X1.1
unnamed: C3.1, Q2.3 (D), R8.2, S1.2 (S), U$1.3 (IN)
PROG_GPIO0: JP1.3, U1.18 (GPIO0)
PROG_RST: JP1.4, U1.1 (RST)
PROG_RX: JP1.6, U1.22 (TXD)
PROG_TX: JP1.5, U1.21 (RXD)
VCC: Q2.2 (S), R5.2, S1.1, SW1.P$2, U2.5 (VCC), X2.1

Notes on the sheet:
Battery Input
Door Switch Input
Edge Detection
Power Latching
Programming Header
MCU ESP-12F
https://electronics.stackexchange.com/questions/519758/improving-edge-detector-with-latching-circuit-for-esp8266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
Voltage Regulation to max. 3,3V
Pairing button Press to power ESP continuously.
Milestone M3
Garage_Door_Sensor
Schottky

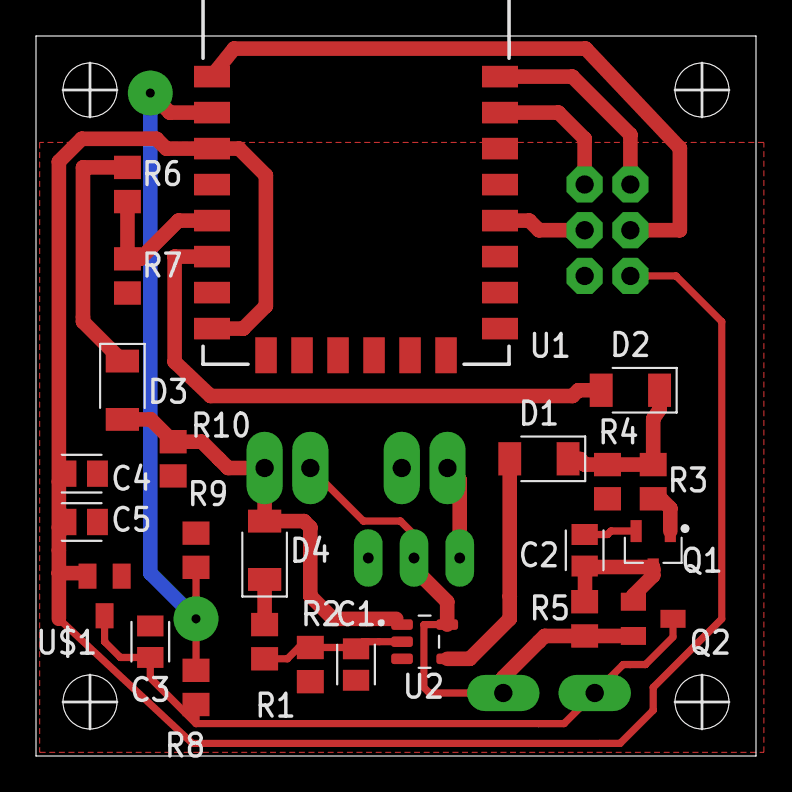
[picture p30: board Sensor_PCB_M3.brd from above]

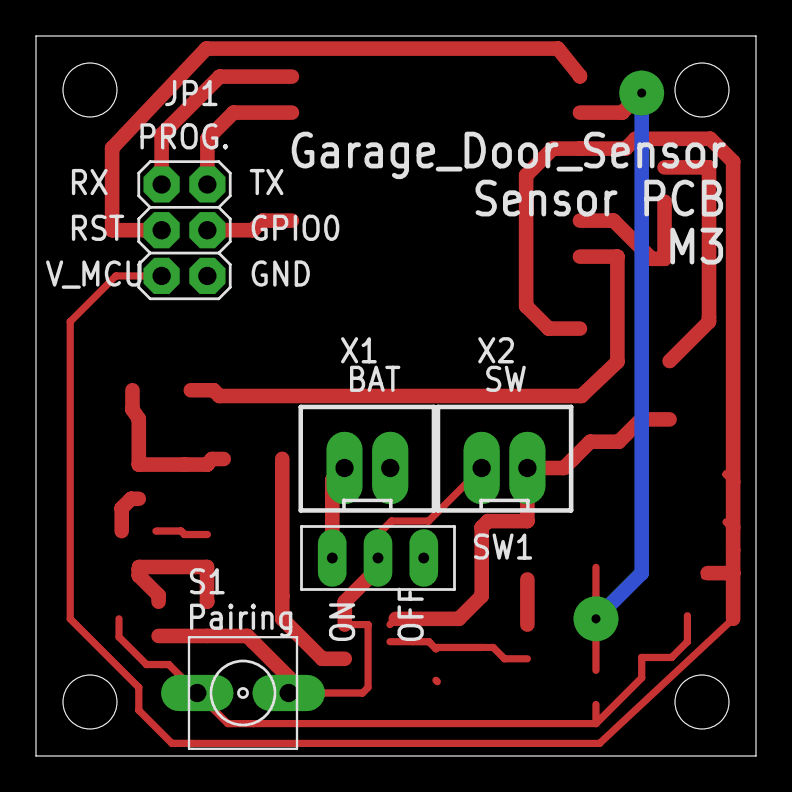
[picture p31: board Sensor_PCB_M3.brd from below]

Board: 2 copper layers, 40.0 x 40.0 mm, 29 parts (5 on the bottom side), 20 nets.

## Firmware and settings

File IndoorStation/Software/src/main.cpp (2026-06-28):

// This is the code that receives all garage door states
// It differentiates between the sensors by their MAC addresses

// https://wolles-elektronikkiste.de/esp-now#multi_transm_1_recv  (Ein Transmitter, ein Receiver – Advanced (ESP32))
// https://randomnerdtutorials.com/esp-now-auto-pairing-esp32-esp8266/

#include <Arduino.h>
#include <espnow.h>
#include <ESP8266WiFi.h>
#include <ESPAsyncWebServer.h>
#include <LittleFS.h>
#include <ArduinoJson.h>
#include <Button2.h>
#include <Schedule.h>
#include "main.h"
#include "config.h"
#include "structures.h"
#include "leds.h"
#include "battery.h"
#include "wifiHandling.h"
#include "timeHandling.h"
#include "otaUpdate.h"
#include "memory.h"
#include "pairing.h"
#include "utils.h"
#include "version.h"

// To increase the FS size https://arduino-esp8266.readthedocs.io/en/latest/filesystem.html#flash-layout

system_config_t sysConfig;

Button2 btn_pairing, btn_reset;             // create button objects

message_sensor_t sensor_message;
message_pairing_t pairing_message;
bool sensor_message_received = false;
bool pairing_message_received = false;
uint8_t received_mac_addr[6];

message_sensor_timestamped_t sensor_messages_latest[NUM_SUPPORTED_SENSORS];

File serverGetDataMemoryFile;
int8_t serverGetDataSensorIndex;
time_t serverGetDataTimeFrom;
time_t serverGetDataTimeTo;
message_sensor_timestamped_t serverGetDataPendingMessage;
bool serverGetDataHasPendingMessage = false;

/**********************************************************************/

void main_updateLeds_sensorStatus()
{
    for(uint8_t i = 0; i < NUM_SUPPORTED_SENSORS; i++)
    {
        if(i >= NUM_SENSOR_LEDS)
        {
            // Only the first NUM_SENSOR_LEDS leds are used for sensor status.
            // If more sensors are supported than NUM_SENSOR_LEDS, the additional sensors are not indicated by leds.
            break;
        }

        switch(sysConfig.sensors[i].mode)
        {
            case SENSOR_MODE_DISABLED: leds_singleOff(i); break;
            case SENSOR_MODE_CHARGING: leds_sensorCharging(i); break;
            case SENSOR_MODE_PAIRING: leds_sensorPairing(i); break;
            case SENSOR_MODE_NORMAL:
            case SENSOR_MODE_ONLY_DISPLAY:
            {
                if(sensor_messages_latest[i].timestamp != -1)
                {
                    bool isOpen = (sensor_messages_latest[i].msg.pinState == SENSOR_PIN_STATE_OPEN);
                    leds_sensorStatus(i, isOpen, battery_isEmpty(sensor_messages_latest[i].msg.batteryVoltage_mV, sysConfig.batteryEmptyThreshold_percent));
                }
                else
                {
                    leds_singleOff(i);
                }
            }
            default: break;
        }
    }
}

void updateLastSensorMessages()
{
    // invalidate all last sensor messages and get the saved ones
    for(uint8_t i=0; i < NUM_SUPPORTED_SENSORS; i++)
    {
        sensor_messages_latest[i].timestamp = -1;

        if(memory_getNumberSensorMessages(i) > 0)
        {
            sensor_messages_latest[i] = memory_getLatestSensorMessagesForSensor(i);
        }
    }

    main_updateLeds_sensorStatus();
}

/**********************************************************************/

void messageReceived(uint8_t* mac_addr, uint8_t* data, uint8 len)
{
    memcpy(&received_mac_addr, mac_addr, sizeof(received_mac_addr));

    // Get the first 4 bytes of the received data and check if it was a pairing message from the sensor
    uint32_t magicNumber = 0;
    if(len >= 4)
    {
        magicNumber = (data[3] << 24) + (data[2] << 16) + (data[1] << 8) + data[0];
    }

    pairing_message_received = false;
    sensor_message_received = false;
    if(magicNumber == PAIRING_MAGIC_NUMBER)
    {
        if (len >= sizeof(pairing_message))
        {
            memcpy(&pairing_message, data, sizeof(pairing_message));
            pairing_message_received = true;
        }
    }
    else
    {
        if (len >= sizeof(sensor_message))
        {
            memcpy(&sensor_message, data, sizeof(sensor_message));
            sensor_message_received = true;
        }
    }
}

/**********************************************************************/

void setSensorMode(uint8_t sensorIndex, SensorModes mode)
{
    if(sensorIndex >= 0 && sensorIndex < NUM_SUPPORTED_SENSORS)
    {
        if(mode == SENSOR_MODE_PAIRING)
        {
            pairing_enablePairingModeForSensor(sensorIndex);
        }
        else
        {
            pairing_disablePairingModeForSensor(sensorIndex);
            sysConfig.sensors[sensorIndex].mode = mode;
            memory_saveSystemConfig(sysConfig);   // Only save if not in pairing mode, because pairing mode is only temporary and should not be saved persistently
        }

        events.send("", SERVER_EVENT_SENSOR_MODE_CHANGED, millis());
        main_updateLeds_sensorStatus();
    }
}

/**********************************************************************/

void btnHandler_reset_longClick(Button2& btn)
{
    memory_removeAllData();
    wifiHandling_eraseCredentials();
    delay(2000);
    ESP.restart();
}

void btnHandler_pairing_longClick(Button2& btn)
{
    // button is pressed long:
    // - if no sensor is in pairing mode, set the first sensor to pairing mode
    // - if at least one sensor is in pairing mode, set all sensors that are in pairing mode to normal mode

    int indexFirstSensorInPairingMode = pairing_findSensorIndexInPairingMode();
    if(indexFirstSensorInPairingMode != -1)
    {
        // at least one sensor is in pairing mode: disable pairing mode for all sensors
        pairing_stopAllSensorsPairingMode();
        events.send("", SERVER_EVENT_SENSOR_MODE_CHANGED, millis());
        main_updateLeds_sensorStatus();
    }
    else
    {
        // no sensor is in pairing mode: enable pairing mode for the first sensor
        setSensorMode(0, SENSOR_MODE_PAIRING);
    }
}

void btnHandler_pairing_click(Button2& btn)
{
    // button is pressed short:
    // - if no sensor is in pairing mode, do nothing
    // - otherwise find the index of the first sensor with pairing mode. Set it to normal mode and set the next sensor to pairing mode. If it was the last sensor begin with the first again.

    int indexFirstSensorInPairingMode = pairing_findSensorIndexInPairingMode();
    if(indexFirstSensorInPairingMode != -1)
    {
        // increment to the next sensor and roll over at the last sensor.
        int indexNextSensor = indexFirstSensorInPairingMode + 1;
        if(indexNextSensor >= NUM_SENSOR_LEDS)
        {
            indexNextSensor = 0;
        }
        setSensorMode(indexNextSensor, SENSOR_MODE_PAIRING);
    }
}

/**********************************************************************/

/**
 * Set default values for the system config (e.g. empty MAC addresses, normal mode for all sensors).
 * @param sysConfig The system config struct, for which the default values are set.
 */
void main_setDefaultSystemConfig(system_config_t& sysConfig)
{
    for(uint8_t i = 0; i < NUM_SUPPORTED_SENSORS; i++)
    {
        memset(sysConfig.sensors[i].mac, 0, sizeof(sysConfig.sensors[i].mac));
        memset(sysConfig.sensors[i].lmk, 0, sizeof(sysConfig.sensors[i].lmk));  // set to all 0 to indicate that no LMK is set for this sensor. A valid LMK must be generated (e.g. with main_makeSureEncryptionKeysAreSetInSystemConfig()).
        sysConfig.sensors[i].mode = SENSOR_MODE_NORMAL;
        sysConfig.sensors[i].isPaired = false;
        sysConfig.sensors[i].useEncryption = false;
        memset(sysConfig.sensors[i].name, 0, sizeof(sysConfig.sensors[i].name));
    }
    memset(sysConfig.pmk, 0, sizeof(sysConfig.pmk));    // set to all 0 to indicate that no PMK is set for this sensor. A valid PMK must be generated (e.g. with main_makeSureEncryptionKeysAreSetInSystemConfig()).
    sysConfig.batteryEmptyThreshold_percent = 15;       // Default to 15%
}

/**
 * Make sure that for all sensors encryption keys (LMK) and a PMK are set in the system config.
 * If not, generate random keys and save them in the system config.
 * This ensures that encryption is possible for all sensors and also prevents that empty keys are used, which are not valid for encryption.
 * @return true if new keys were generated and saved, false if all keys were already set.
 */
bool main_makeSureEncryptionKeysAreSetInSystemConfig(system_config_t& sysConfig)
{
    bool keysGenerated = false;
    for(uint8_t i = 0; i < NUM_SUPPORTED_SENSORS; i++)
    {
        if(utils_isKeyEmpty(sysConfig.sensors[i].lmk, ESPNOW_KEY_LEN))
        {
            // If the sensor has an empty LMK, generate a random LMK and save it in the system config. This ensures that encryption is possible for this sensor.
            utils_generateRandomKey(sysConfig.sensors[i].lmk, ESPNOW_KEY_LEN);
            keysGenerated = true;
        }
    }

    if(utils_isKeyEmpty(sysConfig.pmk, ESPNOW_KEY_LEN))
    {
        // If the PMK is empty, generate a random PMK and save it in the system config. This ensures that encryption is possible.
        utils_generateRandomKey(sysConfig.pmk, ESPNOW_KEY_LEN);
        keysGenerated = true;
    }

    if(keysGenerated)
    {
        // If new keys were generated, save the system config to persist the new keys in memory.
        memory_saveSystemConfig(sysConfig);
    }
    return keysGenerated;
}

/**********************************************************************/

/**
 * Remove an ESP-NOW peer if it exists.
 * It is identified by the MAC address.
 * @param sensorConfig The sensor config struct containing the MAC address for the peer.
 * @return true if the peer was removed successfully (and existed), false otherwise (e.g. no peer existed).
 */
bool main_removePeer(sensor_config_t& sensorConfig)
{
    if (esp_now_is_peer_exist((uint8_t*)sensorConfig.mac))
    {
        esp_now_del_peer((uint8_t*)sensorConfig.mac);
        return true;
    }
    return false;
}

/**
 * Add an encrypted peer with the given MAC address and LMK.
 * If a peer with the given MAC address already exists, it is deleted before adding the new peer.
 * This is important to ensure that the new LMK is used for the peer, especially if they have changed.
 * It is also important to only add a new peer with encryption in WIFI_STA mode.
 * Also not mix the use of esp_now_add_peer() for encrypted and unencrypted peers (seems to distract the ESP8266 encryption)  
 * @param sensorConfig The sensor config struct containing the MAC address and LMK for the peer.
 * @return true if the peer was added successfully, false otherwise.
 */
bool main_addEncryptedPeer(sensor_config_t& sensorConfig)
{
    if(!sensorConfig.useEncryption)
    {
        #ifdef DEBUG_OUTPUT
            Serial.println("No peer added because encryption is disabled for this sensor!");
        #endif
        return false;
    }

    // If the peer already exists → delete it (important for channel change!)
    main_removePeer(sensorConfig);

    int result = -1;
    result = esp_now_add_peer((uint8_t*)sensorConfig.mac, ESP_NOW_ROLE_SLAVE, 0, (uint8_t*)sensorConfig.lmk, ESPNOW_KEY_LEN);

    #ifdef DEBUG_OUTPUT
        Serial.printf("addEncryptedPeer: %02X:%02X:%02X:%02X:%02X:%02X | ch=%d | res=%d\n", sensorConfig.mac[0], sensorConfig.mac[1], sensorConfig.mac[2], sensorConfig.mac[3], sensorConfig.mac[4], sensorConfig.mac[5], wiFiChannel, result);
    #endif

    if (result != 0)
    {
        #ifdef DEBUG_OUTPUT
            Serial.println("ERROR: Failed to add encrypted peer!");
        #endif
        return false;
    }
    return true;
}

/**********************************************************************/

void onUpload(AsyncWebServerRequest *request, String filename, size_t index, uint8_t *data, size_t len, bool final)
{
    // For the first chunk: read sensorIndex from the request and open the file
    if (index == 0)
    {
        int sensorIndex = -1;
        if (request->hasParam("sensorIndex", true))
        {
            sensorIndex = request->getParam("sensorIndex", true)->value().toInt();
        }
        if (sensorIndex >= 0 && sensorIndex < NUM_SUPPORTED_SENSORS)
        {
            // open the file with the correct format (ignoring the uploaded filename) on first call and store the file handle in the request object
            char strBuf[32];
            sprintf(strBuf, FILENAME_HISTORY_SENSOR_FORMAT, sensorIndex);
            request->_tempFile = LittleFS.open(strBuf, "w");
        }
        else
        {
            request->_tempFile = File(); // invalid / empty file object
        }
    }

    if (len > 0 && request->_tempFile)    // write only if data exists AND file was opened successfully
    {
        // stream the incoming chunk to the opened file
        request->_tempFile.write(data, len);
    }

    // Upload finished
    if (final)
    {
        if (request->_tempFile)    // file was opened successfully before
        {
            // close the file handle as the upload is now done
            request->_tempFile.close();
            request->redirect("/system_management.html");     // Only redirect if the file was uploaded. If an invalid sensorIndex was given, the upload ends in the <IP>/upload_data page (white page)
            updateLastSensorMessages();
        }
        else                      // return an error message only if file was NOT opened before
        {
            request->send(200, "text/plain", "Upload failed: Invalid sensorIndex or file could not be written!");
        }
    }
}

/*++++++++++++++++++++++++++++++++++++++++++++++++++++++++++++++++++++*/
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
void loop()
{
    wifiHandling_wifiManagerLoop();
    btn_reset.loop();
    btn_pairing.loop();
    leds.service();
    otaUpdate_loop();

    if(pairing_handlePairingAPTimeout())
    {
        // If the pairing AP timeout occurred, set all sensors that are in pairing mode back to normal mode.
        pairing_stopAllSensorsPairingMode();
        events.send("", SERVER_EVENT_SENSOR_PAIRING_TIMEOUT, millis());
        main_updateLeds_sensorStatus();
    }

    if(sensor_message_received)
    {
        sensor_message_received = false;

        #ifdef DEBUG_OUTPUT
            Serial.printf("Transmitter MAC Address: %02X:%02X:%02X:%02X:%02X:%02X \n\r", received_mac_addr[0], received_mac_addr[1], received_mac_addr[2], received_mac_addr[3], received_mac_addr[4], received_mac_addr[5]);
        #endif
        for(uint i = 0; i < NUM_SUPPORTED_SENSORS; i++)
        {  
            if(sysConfig.sensors[i].isPaired &&
                received_mac_addr[0] == sysConfig.sensors[i].mac[0] && 
                received_mac_addr[1] == sysConfig.sensors[i].mac[1] &&
                received_mac_addr[2] == sysConfig.sensors[i].mac[2] &&
                received_mac_addr[3] == sysConfig.sensors[i].mac[3] &&
                received_mac_addr[4] == sysConfig.sensors[i].mac[4] &&
                received_mac_addr[5] == sysConfig.sensors[i].mac[5] &&
                (sysConfig.sensors[i].mode == SENSOR_MODE_NORMAL || sysConfig.sensors[i].mode == SENSOR_MODE_ONLY_DISPLAY))
            {
                sensor_messages_latest[i].msg = sensor_message;
                time_t now;
                time(&now);
                sensor_messages_latest[i].timestamp = now;
                #ifdef DEBUG_OUTPUT
                    Serial.printf("Data received from Sensor %d \n\r", i);
                #endif
                timeHandling_printSerial(now);
              
                main_updateLeds_sensorStatus();

                if(sysConfig.sensors[i].mode == SENSOR_MODE_NORMAL)
                {
                    memory_addSensorMessage(i, sensor_messages_latest[i]);
                }
                events.send("", SERVER_EVENT_SENSOR_NEW_MESSAGE, millis());
                break;
            }
        }
    }
    else if(pairing_message_received)
    {
        pairing_message_received = false;

        #ifdef DEBUG_OUTPUT
            Serial.printf("Pairing message from MAC Address: %02X:%02X:%02X:%02X:%02X:%02X \n\r", received_mac_addr[0], received_mac_addr[1], received_mac_addr[2], received_mac_addr[3], received_mac_addr[4], received_mac_addr[5]);
        #endif

        // Check if the received MAC address matches the sensorMac in the pairing message payload. If not, ignore the message.
        // This prevents that random pairing messages from other devices are processed, which could cause issues (e.g. if the sender MAC matches a sensor that is currently in pairing mode, but the sender is not the actual sensor trying to pair).
        if(memcmp(received_mac_addr, pairing_message.sensorMac, sizeof(received_mac_addr)) != 0)
        {
            // The sender MAC does not match the sensorMac in the payload, ignore the message.
            #ifdef DEBUG_OUTPUT
                Serial.println("Pairing message ignored: sender MAC does not match sensorMac in payload.");
            #endif
            return;
        }
        if(pairing_message.pairingToken != pairing_currentToken)
        {
            // The token in the payload does not match the current pairing token, ignore the message. This prevents that old pairing messages are processed, which could cause issues (e.g. if the sender is an old sensor that was in pairing mode before but is now trying to pair again, the old message with the old token could be received after the new token is generated and processed, which would cause that the new sensor is paired with the old message).
            #ifdef DEBUG_OUTPUT
                Serial.println("Pairing message ignored: token in payload does not match current pairing token.");
            #endif
            return;
        }

        for(int sensorIndex = 0; sensorIndex < NUM_SUPPORTED_SENSORS; sensorIndex++)
        {
            if(sysConfig.sensors[sensorIndex].mode == SENSOR_MODE_PAIRING)
            {
                // save the received MAC address for the sensor which is in pairing mode and reset the sensor mode back to normal
                memcpy(sysConfig.sensors[sensorIndex].mac, received_mac_addr, 6 * sizeof(uint8_t));
                sysConfig.sensors[sensorIndex].isPaired = true;
                sysConfig.sensors[sensorIndex].useEncryption = true;
                memory_saveSystemConfig(sysConfig);

                pairing_disablePairingModeForSensor(sensorIndex);

                main_addEncryptedPeer(sysConfig.sensors[sensorIndex]);

                events.send("", SERVER_EVENT_SENSOR_PAIRED, millis());
                break;
            }
        }
    }
}

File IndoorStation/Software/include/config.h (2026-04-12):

#ifndef CONFIG_H
#define CONFIG_H

#include <Arduino.h>

#define BTN_PAIRING_PIN         12                        // The pin which is used for the pairing button
#define BTN_WIFI_PIN            13                        // The pin which is used for the Wifi button
#define BTN_RESET_PIN           16                        // The pin which is used for the reset button

#define SENSOR_PIN_STATE_OPEN   LOW                       // This pin state of the sensor is interpreted as open door
#define NUM_SUPPORTED_SENSORS   3                         // The number of supported sensors

#define CONNECTION_TIMEOUT_MS   10000                     // Timeout in ms for connection to router
#define WIFI_HOSTNAME           "Garagen Tor Status"      // Name that is displayed for this device by the router
#define CONFIGURATION_AP_NAME   "Garagen Tor Status AP"   // Name for the configuration access point
#define CONFIGURATION_AP_PW     ""                        // Password for the configuration access point

#define PAIRING_AP_NAME_BASE    "GaragenTorPairing-"      // Base name for the pairing access point (it is appended by the chip id to make it unique)
#define PAIRING_AP_PW           "Pa1rng#PW"               // Password for the pairing access point
#define PAIRING_AP_TIMEOUT_MS   60000                     // Timeout in ms for the pairing access point. Use 0 to disable the timeout and keep the AP active until it is manually stopped.

// https://forum.arduino.cc/t/finding-the-size-of-multi-dimensional-array/395465/8
#define ARRAY_ELEMENT_COUNT(array) (sizeof array / sizeof array[0])

//#define DEBUG_OUTPUT                                      // enable this define to print debugging output on the serial. If this is disabled, no serial output is used at all (to save power)

#endif

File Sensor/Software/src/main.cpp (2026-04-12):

// This is the code that sends the garage door state to the indoor station
// The same code can be used for each sensor (the indoor station differentiates between the sensors by their MAC addresses)

// CAUTION: Copy and adapt the addresses_Template.h file in the include folder!!!

// https://wolles-elektronikkiste.de/esp-now#multi_transm_1_recv  (Ein Transmitter, ein Receiver – Advanced (ESP32))

#include <Arduino.h>
#include <espnow.h>
#include <ESP8266WiFi.h>
#include "pairing.h"
#include "version.h"
#include "config.h"

// Packing of this structure reduces the size to 5 bytes
PACK_STRUCT_BEGIN
typedef struct message_sensor
{
    PACK_STRUCT_FIELD(bool pinState);                 // This field contains the state of the sensor (door open / closed)
    PACK_STRUCT_FIELD(uint16_t batteryVoltage_mV);    // This field contains the measured battery voltage in mV
    PACK_STRUCT_FLD_8(uint8_t numberSendLoops);       // This field contains the total number of loops needed to send the message to the indoor station
    PACK_STRUCT_FLD_8(uint8_t sensor_sw_version);     // This field contains the software version of the sensor in the following format: Upper 4 bits contain the Major number, lower 4 bits contain the Minor number (each number can be in the range from 0..15)
}PACK_STRUCT_STRUCT message_sensor_t;
PACK_STRUCT_END

PACK_STRUCT_BEGIN
typedef struct message_pairing
{
    PACK_STRUCT_FIELD(uint32_t pairingMagicNumber);         // This field contains a fixed number (0xCAFEBEEF). Only if this number is found, the MAC of the received message is saved by the Indoor Station.
    PACK_STRUCT_FIELD(uint32_t pairingToken);               // This field contains a token for pairing validation. The indoor station generates a random token for each pairing session. The sensor must include this token in the pairing message. The indoor station only accepts the pairing message if the token is correct. This prevents that an attacker can send a pairing message with the correct magic number and a random MAC address to pair with the indoor station without knowing the token.
    PACK_STRUCT_FIELD(uint8_t sensorMac[6] = {0});          // This field contains the MAC address of the sensor which wants to pair. The indoor station saves this MAC address in the system config to identify the sensor in the future and to display the correct MAC address in the web interface.
}PACK_STRUCT_STRUCT message_pairing_t;
PACK_STRUCT_END

bool messageSentReady;
bool messageSentSuccessful;

bool isLedOn;
void setLedState(bool on)
{
    isLedOn = on;
    digitalWrite(LED_BUILTIN, isLedOn ? LOW : HIGH);
}
void toggleLedState()
{
    isLedOn = !isLedOn;
    setLedState(isLedOn);
}

void OnDataSent(uint8_t* macAddr, uint8_t status)
{
    messageSentSuccessful = (status == 0);
    messageSentReady = true;
}

/**
 * Turn the WiFi completely off.
 * https://www.instructables.com/ESP8266-Pro-Tips/ (Step 7)
 */
void WiFiOff()
{
    // "From the experiments, it was found that both WiFi.mode() and WiFi.forceSleepBegin() were required in order to switch off the radio. 
    // The forceSleepBegin() call will set the flags and modes necessary, but the radio will not actually switch off until control returns to the ESP ROM. 
    // To do that we’re adding a delay(1), but I suppose a yield() would work as well."
    WiFi.mode(WIFI_OFF);
    WiFi.forceSleepBegin();
    delay(1);
}

/**
 * Turn the WiFi on.
 * https://www.instructables.com/ESP8266-Pro-Tips/ (Step 7)
 */
void WiFiOn()
{
    WiFi.forceSleepWake();
    delay(1);
    WiFi.mode(WIFI_STA);
    WiFi.disconnect();
}

/**
 * Reinitialize ESP-NOW to the requested WiFi channel.
 * @param wifiChannel WiFi channel that is used for the ESP-NOW connection. This must match the receiver channel that depends on the channel used by the router.
 * @param forceUnencrypted If true, the peer will be added without encryption. This is used for pairing messages (the indoor station will be in AP mode then and isn't able to receive encrypted messages).
 */
void initEspNow(uint8_t wifiChannel, bool forceUnencrypted)
{
    WiFi.mode(WIFI_STA);
    WiFi.disconnect();
    delay(1);

    // set WiFi channel
    wifi_promiscuous_enable(1);
    wifi_set_channel(wifiChannel);
    wifi_promiscuous_enable(0);

    // If the peer already exists → delete it (important for channel change!)
    if (esp_now_is_peer_exist((uint8_t*)PairingInfo.indoor_station_mac))
    {
        esp_now_del_peer((uint8_t*)PairingInfo.indoor_station_mac);
    }

    int result = -1;
    if(!utils_isKeyEmpty(PairingInfo.lmk, ESPNOW_KEY_LEN) && !utils_isKeyEmpty(PairingInfo.pmk, ESPNOW_KEY_LEN) && !forceUnencrypted)
    {
        result = esp_now_add_peer(PairingInfo.indoor_station_mac, ESP_NOW_ROLE_SLAVE, 0, PairingInfo.lmk, ESPNOW_KEY_LEN);

        #ifdef DEBUG_OUTPUT
            char pmkHex[2 * ESPNOW_KEY_LEN + 1];
            utils_bytesToHex(PairingInfo.pmk, ESPNOW_KEY_LEN, pmkHex);
            char lmkHex[2 * ESPNOW_KEY_LEN + 1];
            utils_bytesToHex(PairingInfo.lmk, ESPNOW_KEY_LEN, lmkHex);
            Serial.printf("[Main] Add peer with encryption: pmk=%s, lmk=%s\n", pmkHex, lmkHex);
        #endif
    }
    else
    {
        result = esp_now_add_peer(PairingInfo.indoor_station_mac, ESP_NOW_ROLE_SLAVE, 0, NULL, 0);
        
        #ifdef DEBUG_OUTPUT
            Serial.println("[Main] Add peer without encryption.");
        #endif
    }

    if(result != 0)
    {
        #ifdef DEBUG_OUTPUT
            Serial.println("[Main] Failed to add peer");
        #endif
    }
}

/**
 * Read the ADC value and average it 16 times
 * https://www.esp8266.com/viewtopic.php?p=80628
 */
int readADC()
{
    int a;
    int i;
    
    a = analogRead(A0);
    a = 0;
    for(i=0; i<16; i++) 
    {
        a += analogRead(A0);
    }
    return a>>4;
}

/**
 * Get the battery voltage by measuring the ADC value and scaling it by the resistor divider.
 * ADC_RESISTOR_R8 is from the battery voltage to the ADC input.
 * ADC_RESISTOR_R9 is from the ADC input to GND.
 */
float getBatteryVoltage()
{
    int adcReadVal = readADC();
    float adcVoltage_V = adcReadVal / 1023.0f;
    float batteryVoltage_V = adcVoltage_V * ((ADC_RESISTOR_R8 + ADC_RESISTOR_R9) / ADC_RESISTOR_R9);

    #ifdef DEBUG_OUTPUT
        Serial.printf("[Main] ADC value=%d, ADC Voltage=%f V, Battery Voltage=%f V\n", adcReadVal, adcVoltage_V, batteryVoltage_V);
    #endif
    return batteryVoltage_V;
}
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

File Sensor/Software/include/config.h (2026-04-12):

#ifndef CONFIG_H
#define CONFIG_H

#include <Arduino.h>

#define MCU_LATCH_PIN       12      // GPIO 12
#define DOOR_SWITCH_PIN     14      // GPIO 14
#define MAX_SEND_RETRIES    10      // Number of send retries for each channel before changing to the next channel
#define MAX_WIFI_CHANNELS   13      // 13 in Europe, 11 for North America (adapt the following list accordingly)
uint8_t const wifi_channel_order[] = { 1, 6, 11, 2, 3, 4, 5, 7, 8, 9, 10, 12, 13};      // First try to use the channels 1, 6 and 11 to send (these are the most assigned ones by routers)

#define ADC_RESISTOR_R8     390.0f  // Resistor value in kOhm, from the battery voltage to the ADC input
#define ADC_RESISTOR_R9     100.0f  // Resistor value in kOhm, from the ADC input to GND

#define PAIRING_AP_NAME_BASE            "GaragenTorPairing-"        // Base name for the pairing access point (should be the same as in the indoor station software to find the correct AP)
#define PAIRING_AP_PW                   "Pa1rng#PW"                 // Password for the pairing access point (should be the same as in the indoor station software)
#define PAIRING_CONNECT_TIMEOUT_MS      15000                       // Timeout for connecting to the pairing access point in milliseconds

#define DEBUG_OUTPUT                                      // enable this define to print debugging output on the serial. If this is disabled, no serial output is used at all (to save power)

#endif

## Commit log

2023-12-16 First commit containing the initial code for both the sensor and indoor station
2023-12-19 Added states for build in LED for debugging
2023-12-22 Updated sensor code (try to send data multiple times if not successful at the first try)
2024-01-11 Added MCU_LATCH_PIN for Sensor, changed message_t to containg numberSendLoops
2024-01-13 Updated sensor code (door switch pin shouldn't have an pullup resistor)
2024-01-14 Added electrical files (milestone M1)
    [IndoorStation_PCB_M1.brd, IndoorStation_PCB_M1.sch, Sensor_PCB_M1.brd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]
2024-01-28 Updated indoor station code (Corrected some pin numbers, added initialisation for button pins)
    [main.cpp]
2024-02-06 Updated indoor station code (Added library for basic button handling)
2024-02-06 Updated indoor station code (first sensor pairing constructs)
2024-02-09 Updated indoor station code (improved LED handling by separating to extra files and using WS2812FX library)
2024-02-11 Updated indoor station code (improved sensor pairing control by syncing button presses with website interaction)
2024-02-19 Updated sensor code (loop over all wifi channels while sending data until success)
2024-02-25 Updated sensor code (measure real battery voltage via ADC and resistor divider)
2024-03-01 Updated layout and show timestamp on index.html, timestamp sensor messages now
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2024-03-05 First working draft for memory module (save last received sensor_messages)
2024-03-11 Adapted the ESP hostname displayed by the router, corrected Wifi disconnected LED status when AP is open
    [config.h, main.cpp, wifiHandling.cpp]
2024-03-13 First attempts for displaying sensor history data on web page
2024-03-15 Added input fields to enter the sensor MAC addresses, save and load the sensor mac addresses
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2024-03-23 Added feature for sensor data download and upload
2024-03-25 Fixed timezone for charts, improved get_data server endpoint, changed wifi hostname
    [config.h, main.cpp]
2024-03-26 Updated electrical files (milestone M2)
    [IndoorStation_PCB_M1.brd, IndoorStation_PCB_M1.sch, IndoorStation_PCB_M2.brd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]
2024-03-26 Added mechanical files (milestone M1)
    [Back_Lid_M1.f3d, Back_Lid_M1.stl, Back_Lid_Text_M1.stl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]
2024-03-26 Added version placeholders for sensor and indoor station, cleaned indoor station code (removed most button handlers, improved some html)
2024-03-27 Removed delay after sensor data sending, display MAC address of sensor on each power up
2024-04-02 Addes some more error handling for webserver endpoints
    [main.cpp]
2024-04-02 Reworked sensor history charts (support chart filtering for dates and sensors now)
2024-04-02 Removed server sent events and insert index.html values via processor
2024-04-04 Show warning on index.html if no MAC was configured for the sensor
2024-04-06 Sending software version from sensor to indoor station and display it on the web pages
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2024-04-14 Bugfix for chart update (only first sensor values were displayed correctly)
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2024-05-06 Updated electrical files (milestone M3)
    [IndoorStation_PCB_M2.brd, IndoorStation_PCB_M2.sch, IndoorStation_PCB_M3.brd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]
2024-05-17 Added mechanical files (milestone M2)
    [Back_Lid_M1.f3d, Back_Lid_M1.stl, Back_Lid_M2.f3d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]
2024-05-18 Added feature to pair sensor with indoor station (send sensor MAC to indoor station)
2024-05-18 Reactivated and renamed button to select pairing mode
2024-05-18 Improved sensor code (combine methods to send pairing and status data, switch off and on Wifi to improve ADC accuracy)
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2024-05-24 Bugfixes for reset of indoor station
    [main.cpp, memory.cpp]
2024-05-25 Added mechanical files (milestone M3)
    [Back_Lid_M2.f3d, Back_Lid_M2.stl, Back_Lid_M3.f3d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]
2024-07-06 Added DEBUG_OUTPUT define for IndoorStation code, disabled DEBUG_OUTPUT for sensor to save power
2024-07-21 Updated QR code image (smaller QR code with lower redundance), added .stl files to print the QR code for the indoor station
    [qrcode-base.stl, qrcode-frame.stl, qrcode.stl]
2024-08-05 Bugfix for sensor_history.js (chart was incomplete or contained wrong data when incomplete chunks were received)
2026-03-16 Adapted chart appearance for sensor_history webpage (disable animations, use stepped line and disable grouping for pinState chart), added logic to only return a specific portion of the sensor_history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
2026-03-18 Reworked /get_data endpoint on ESP (sometimes with date filters no messages were sent)
    [main.cpp]
2026-03-27 Adapted logic to only return a specific portion of the sensor_history (radio buttons for date ranges)
2026-03-27 Added dialog to confirm deletion of sensor data (and changed /remove_data endpoint to HTTP_POST)
2026-03-29 Changed website handling to dynamically generate the number of sensor cards and chart series retreived from the ESP
2026-03-29 Show icons for loading, inactive or pairing sensor state on overview page (#3), different small bugfixes
    [main.cpp]
2026-03-30 Moved upload data functionality on webpages to each sensor and added mock_server functionality for upload
2026-03-30 SensorIndex was sometimes 1-based (now it's 0-based everywhere)
2026-03-30 Changed display style for buttons and mac address save on management webpage
2026-03-30 Corrected upload endpoint logic on ESP, small webpage adaptions
    [main.cpp]
2026-04-01 Added some checks to ESP code (invalid sensor files or indices)
2026-04-06 Improved sensor pairing logic (sensor can query the indoor station mac via a access point now during pairing, pairing info save in the Sensor EEPROM)
2026-04-06 Indoor Station: Only allow one sensor slot in pairing mode at the same time
2026-04-06 Persist the configured sensor modes, small bugfix for index webpage
    [main.cpp, memory.cpp]
2026-04-07 Update webpage after sensor pairing or when new message received
2026-04-07 Added icons for sensor modes, update webpages on sensor mode changes
2026-04-09 Changed memory format used to persist the system configuration (sensor macs, sensor modes, ...)
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2026-04-14 Added feature to assign names to the sensor slots (#8)
2026-04-16 Bugfix for corrupted sensor messages (only add encrypted sensors as peers, unencrypted data is received directly), added size check for received data (#13)
    [main.cpp]
2026-04-16 Restructured system_management webpage layout and added possibility to remove a sensor (#7), disabled data grouping for accu chart
2026-04-17 Made low battery threshold configurable and show warning icon on index.html (#11), removed voltage info from index.html
